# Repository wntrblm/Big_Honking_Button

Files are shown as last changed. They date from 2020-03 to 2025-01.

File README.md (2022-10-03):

# Winterbloom Big Honking Button

Winterbloom Big Honking Button is an open-source Eurorack module. You can find out more at https://honk.wntr.dev/.

## License and contributing

The code here is available under the [MIT License](firmware/LICENSE), the hardware designs are available under [CC BY-SA 4.0](hardware/LICENSE). I welcome contributors, please read the [Code of Conduct](CODE_OF_CONDUCT.md) first. :)

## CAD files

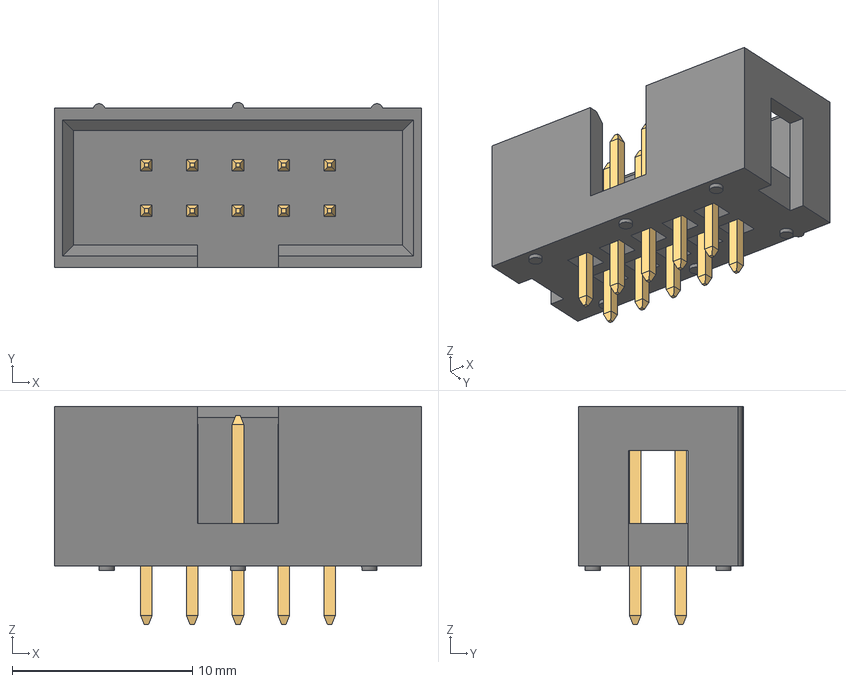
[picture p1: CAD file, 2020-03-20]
hardware/board/3dmodels/wurth-61201021621.step
20.4 x 9.18 x 12.1 mm
6120xx21621_PIN x 10

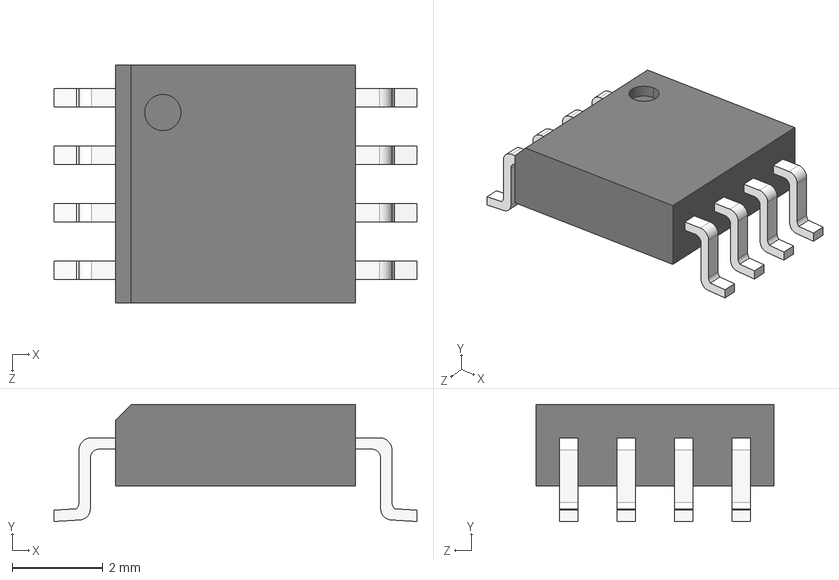
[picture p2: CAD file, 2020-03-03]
hardware/board/3dmodels/soic-8.step
8.00 x 2.58 x 5.25 mm

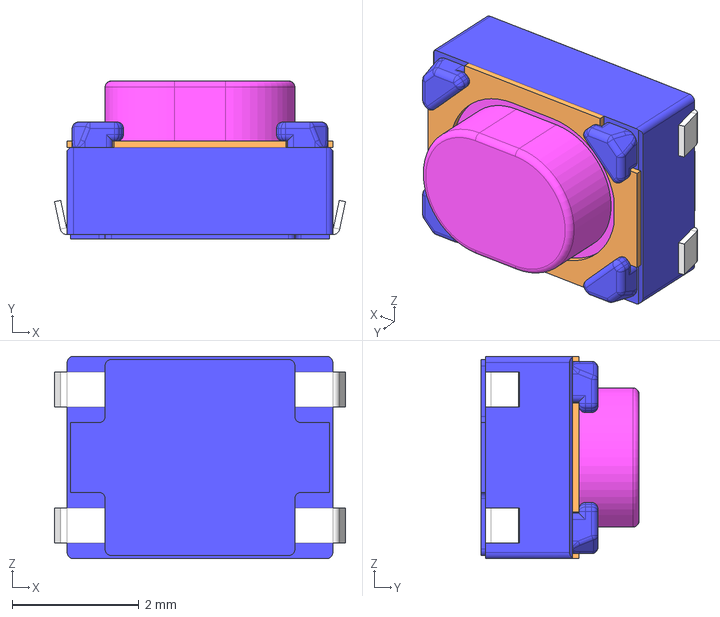
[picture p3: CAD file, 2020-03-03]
hardware/board/3dmodels/smt_tact.step
4.60 x 2.50 x 3.20 mm

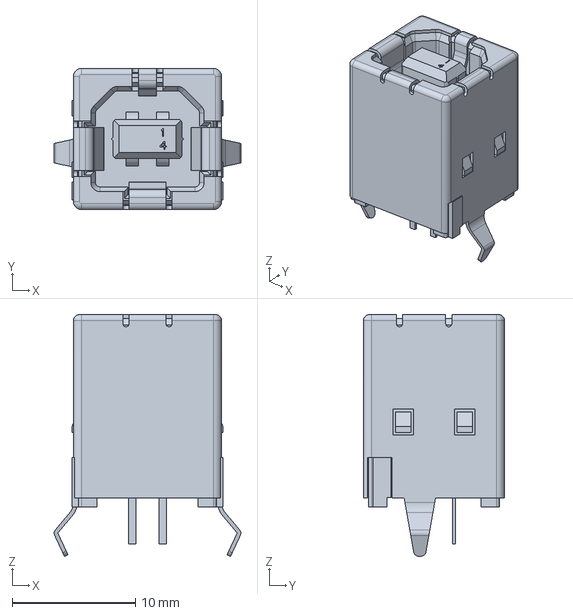
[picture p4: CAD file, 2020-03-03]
hardware/board/3dmodels/c-5787834-1-c-3d.step
15.1 x 11.5 x 19.6 mm

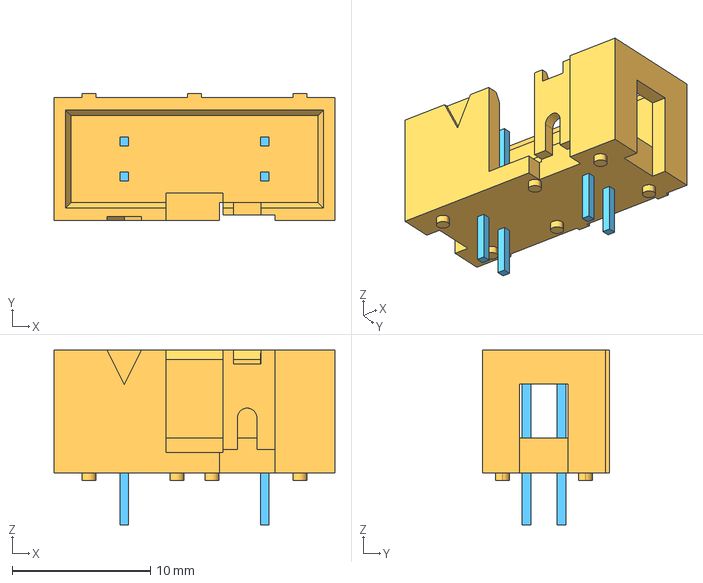
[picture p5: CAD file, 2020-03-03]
hardware/board/3dmodels/eurorack-power.step
20.3 x 9.20 x 12.6 mm

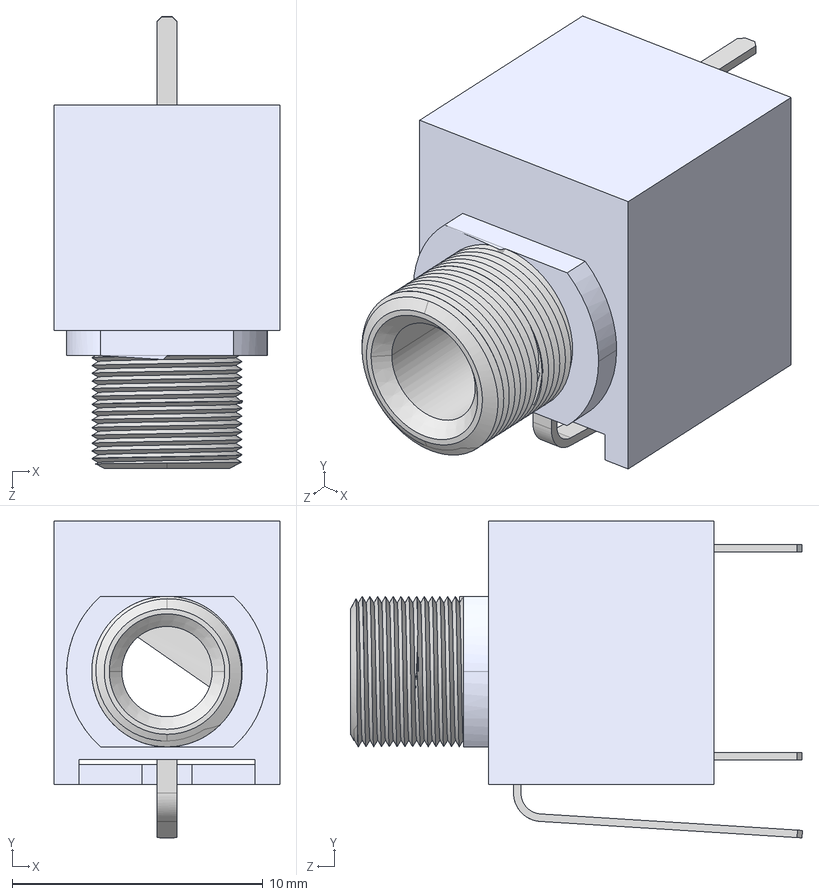
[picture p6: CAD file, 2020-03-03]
hardware/board/3dmodels/User Library-PJ301M-12 Thonkiconn v0_2.STEP
9.00 x 12.6 x 18.0 mm

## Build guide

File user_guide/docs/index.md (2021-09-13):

# Big Honking Button User Guide

Big Honking Button is, well, a big button that honks. Okay, that's not all- it’s actually a simple sampler in a very silly package. It has pitch CV, gate in, gate out, and you can store up to 4mb of samples on it.

## Getting support and help

We want you to have a wonderful experience with your module. If you need help or run into problems, please reach out to us. Email is the best way for product issues, whereas Discord and GitHub are great for getting advice and help on how to customize your module.

-   Send us [an email](mailto:support@winterbloom.com).
-   File a bug [on GitHub](https://github.com/wntrblm/Big_Honking_Button/issues)
-   Reach out on the [Discord][discord]

## Installing the module

To install this into your Eurorack setup:

1. Connect a Eurorack power cable to your power supply and the back of the module. **Note that even though the power connector on the module is keyed, double check that the red stripe is on the side labeled `red stripe`!**
1. Screw the module to your rack's rails.

## Inputs and outputs

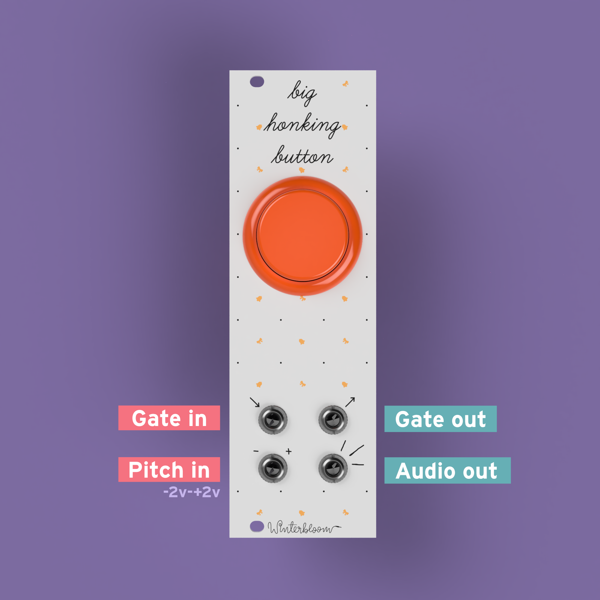
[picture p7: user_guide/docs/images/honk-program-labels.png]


Big Honking Button has two inputs:

-   A gate / trigger in
-   A pitch CV in that is 1v/Oct with a `-5v` to `+5v` range<sup>see note</sup>

And two outputs:

-   A gate / trigger out (`0v` or `5v`)
-   An audio out

With the default code, it will trigger the sample and play it through the audio out whenever the button is pressed or whenever the gate input is triggered. It will also set the gate out to high whenever the button is pressed or whenever the gate in is high. You can customize some of this behavior by [modifying the code](#modifying-the-code).

!!! note "Revision differences"
    Big Honking Buttons manufactured prior to 2021 (marked v4 on the backside) only have an input range of `-2v` to `+2v`. More than that won't damage the module, but it won't be able to measure anything outside of that range.

## Changing the sample

You can change the sample on Big Honking Button by connecting it to your computer via a micro USB cable. The USB port is located on the module's main circuit board, located under the panel. Please note that you do have to power the module in order for the USB connection to work - the module doesn't draw any power from the USB port.

Samples must be in mono, 16-bit, 44.1kHz, signed `wav` files. Adafruit has an [excellent guide on how to convert sound files](https://learn.adafruit.com/adafruit-wave-shield-audio-shield-for-arduino/convert-files), though your sample can be 44.1kHz and not 22kHz.

To modify the sample that plays:

1. Connect the Big Honking Button to your computer using a micro USB cable. It should show up as a small external drive named `CIRCUITPY`
1. Navigate to the `samples` folder in the drive
1. Rename or delete the existing `honk.wav` file
1. Copy your sample over and rename it to `honk.wav`

Your Big Honking Button will reboot and then it should play the new sample! If you run into trouble, please [reach out](#getting-support-and-help).

You can store and play multiple samples on the Big Honking Button, but to do that, you'll need to learn how to modify some of the code - don't worry! It's not too hard.

## Modifying the code

When connected to your computer, Big Honking Button shows up as a small drive named `CIRCUITPY`. In that drive, you should find a file named `code.py`. Big Honking Button runs [CircuitPython][circuitpython] which means that its firmware is written in the approachable [Python](https://python.org) programming language and you don't need any special knowledge or compilers to make changes to it. So, open up that file in your favorite text editor, we're going to make some changes!

If you don't have a text editor - that's okay! While you could use Notepad (Windows) or TextEdit (Mac), these can sometimes have issues with CircuitPython devices like Big Honking Button. I'd recommend [installing Mu](https://learn.adafruit.com/welcome-to-circuitpython/installing-mu-editor) if you're new to this whole world. You can read more about editing code for CircuitPython in [Adafruit's guide](https://learn.adafruit.com/welcome-to-circuitpython/creating-and-editing-code).

As a way to get your feet let's change how the Big Honking Button behaves. By default, when you press the button it plays the _entire_ sample, even if you release the button while the sample is still playing (this is **trigger mode**). This will make it where the sample will stop as soon as you let go of the button (or **gate** mode).

In the `code.py` you should see some code that looks like this (it's at the bottom):

```python
if bhb.released:
    bhb.gate_out = False
    # Uncomment the call to stop to make the sample
    # stop playing as soon as you release the button.
    # bhb.stop()
```

Modify this code so that it looks like this:

```python
if bhb.released:
    bhb.gate_out = False
    # Uncomment the call to stop to make the sample
    # stop playing as soon as you release the button.
    bhb.stop()
```

!!! warning "Be careful"
    Python is _whitespace-sensitive_. That means tabs and spaces are important! Make sure that you don't accidentally change the indentation level of this line.

Okay, save the file! Your Big Honking Button should restart and now it should stop the sample as soon as you let go of the button, try pressing it rapidly to see the effect.

!!! note "Tip"
    If things aren't working, see the section below on finding problems or [reach out](#getting-support-and-help)!

**Congrats**, you've made your first change to how the module works! 🎉

Big Honking Button can do all sorts of neat stuff by changing its code. Check out the [examples](#examples) or jump in the deep end with the [code reference](#code-reference). Don't be afraid to experiment and reach out if you need any help!

If you want to you can learn more about [CircuitPython](https://learn.adafruit.com/welcome-to-circuitpython/overview) to the most of your module. Also, please come chat on the [Discord][discord] where you can ask questions and see what others are doing with their Big Honking Button!

## Examples

Big Honking Button can do all sorts of things! We've made a few examples to show you some of the things it can do:
<video controls="" width="100%" style="margin: 1.5em 0;">
    <source src="https://storage.googleapis.com/files.winterbloom.com/marketing/honk-examples.mp4" type="video/mp4">
    Sorry, your browser doesn't support embedded videos.
</video>

To use these examples, connect your Big Honking Button to your computer just like you would when [modifying the code](#modifying-the-code). Once connected, copy the contents of the example you want to try (linked below) to `code.py` on the `CIRCUITPY` drive. **Be sure to save it as the correct name,** if you don't name it `code.py` it won't change anything. If you want to restore the original `code.py` it is [here](https://github.com/wntrblm/Big_Honking_Button/blob/main/examples/default.py).

1. [Cycle example](https://github.com/wntrblm/Big_Honking_Button/blob/main/examples/cycle.py): Shows how to load multiple samples and cycle between them.
1. [Random example](https://github.com/wntrblm/Big_Honking_Button/blob/main/examples/random.py): Shows how to load multiple samples and choose one at random.
1. [CV select example](https://github.com/wntrblm/Big_Honking_Button/blob/main/examples/cv_select.py): Shows how to load multiple samples and use the CV input to select which one to play.
1. [Press & release example](https://github.com/wntrblm/Big_Honking_Button/blob/main/examples/press_release.py) shows how to play a different sample when pressing the button and releasing the button.
1. [Separate button & gate example](https://github.com/wntrblm/Big_Honking_Button/blob/main/examples/button_gate.py) shows how to play a different sample depending on if the button was pressed or the gate in was triggered.
1. [Burst example](https://github.com/wntrblm/Big_Honking_Button/blob/main/examples/honk_burst.py) shows how to play a "burst" of samples when the button is pressed.
1. [Tap tempo example](https://github.com/wntrblm/Big_Honking_Button/blob/main/examples/tap_tempo.py): Shows how to use the button to set the tempo and have the module play back a sample at each beat.
1. [Sine example](https://github.com/wntrblm/Big_Honking_Button/blob/main/examples/sine.py): An advanced example that shows how to generate a custom waveform.
1. [Noise example](https://github.com/wntrblm/Big_Honking_Button/blob/main/examples/noise.py): An advanced example that shows how to generate noise.

If you're ready to go beyond the examples, check out the [code reference](#code-reference).

## Help! I changed some code and this thing isn't working!

There's probably some sort of error in the program. Don't worry, you can get it figured out.

If you connect using the [serial console](https://learn.adafruit.com/welcome-to-circuitpython/kattni-connecting-to-the-serial-console) you should be able to see the error. If you don't see it right away, you might need to reset the board (either by pressing the little button on the bottom of the module or power cycling your synth). Sometimes you can press `Ctrl+C` followed by `Ctrl+D` in the serial console to get the board to reset and tell you the error.

In any case, reach out on [Discord][discord] and we can walk you through figuring out what went wrong.

## Code reference

Big Honking Button runs [CircuitPython](https://circuitpython.org) and provides a helpful `BigHonkingButton` class for accessing the hardware and features. The first thing that you'll do in your code is import that class and create an instance:

```python
import winterbloom_bhb

bhb = winterbloom_bhb.BigHonkingButton()
```

In a lot of cases, the first thing you'll do with the `bhb` instance is load some samples:

```python
honk = bhb.load_sample("samples/honk.wav")
clap = bhb.load_sample("samples/clap.wav")
```

Once you're all set up, you'll start the **update loop**:

```python
while bhb.update():
    ...
```

This loop will repeat over and over. Each time the loop is run, `bhb.update()` is called and it will read in the state of the button, gate in, and CV input. You have to call `bhb.update()` otherwise it won't ever know if things change!

### Inputs

While inside the loop you can check the state of the various inputs. First, you can check if **either** the button has been pressed **or** the gate in has gone from low to high:

```python
if bhb.triggered:
    ...
```

Similarly, you can check if **either** the button has been released **or** the gate has gone from high to low:

```python
if bhb.released:
    ...
```

These two states are demonstrated in the [default example](https://github.com/wntrblm/Big_Honking_Button/blob/main/examples/default.py):

```python
while bhb.update():
    if bhb.triggered:
        bhb.play("honk.wav")

    elif bhb.released:
        bhb.stop()
```

You can get more specific by checking the button and gate independently. You
can use the `button` property to check the button:

```python
if bhb.button.pressed:
    # Button was just pressed.
    ...

if bhb.button.released:
    # Button was just released.
    ...

if bhb.button:
    # Button is held down.
```

Likewise, you can use the `gate_in` property to check the gate input:

```python
if bhb.gate_in.rising_edge:
    # Gate in just moved from low to high.
    ...

if bhb.gate_in.falling_edge:
    # Gate in just moved from high to low.
    ...

if bhb.gate_in:
    # The gate input is being held high.
```

!!! Note "Aliases"
    For convenience, `bhb.button` and `bhb.gate_in` have property aliases. `.pressed`, `.rising_edge`, and `.triggered` are all the same, likewise, `.released` and `.falling_edge` are the same.

The pitch CV input is a little different. You can use `bhb.pitch_in` to read the *voltage* on the pitch CV input. Remember, the input range is `-5v` to `+5v`.

```python
if bhb.pitch_in > 0:
    ...
```

More usefully you can use the pitch input to re-pitch the sample:

```
bhb.play(honk, pitch_cv=bhb.pitch_in)
```

There are other ways you can use the CV input, for instance, the [CV select example](https://github.com/wntrblm/Big_Honking_Button/blob/main/examples/cv_select.py) uses it to select from a list of samples.

### Outputs

Big Honking Button has two outputs: an audio out and a gate out. The audio out can be used to play previously-loaded samples:

```python
bhb.play(honk)
```

It can also play the sample repeatedly:

```python
bhb.play(honk, repeat=True)
```

And re-pitch the sample:

```python
# Play at twice the frequency
bhb.play(honk, pitch_cv=2.0)

# Play at half the frequency
bhb.play(honk, pitch_cv=0.5)

# Play at normal pitch
bhb.play(honk, pitch_cv=1.0)
```

By default, the sample will play all the way through. If you want to stop the
sample you can use `bhb.stop()`:

```python
if bhb.pressed:
    bhb.play(some_long_sample)

elif bhb.released:
    bhb.stop()
```

When `stop()` is called the sample stops playing immediately - even if its in the middle of playback. If you play a new sample while a sample is playing, the old sample will stop immediately and the new one will start playing.

Finally, there's the gate out:

```python
if bhb.pressed:
    # Sets the output to +5v
    bhb.gate_out = True

elif bhb.released:
    # Sets the output to 0v
    bhb.gate_out = False
```

## Updating the firmware

Updating the firmware requires two steps: Updating CircuitPython and updating Big Honking Button's libraries.

### Updating CircuitPython

1. [Download the latest version of CircuitPython for Winterbloom Big Honking Button](https://circuitpython.org/board/winterbloom_big_honking_button/).
1. Connect Big Honking Button to your computer via USB. The USB port is located underneath the panel. Note that you still have to power the module from a Eurorack power supply.
1. Place Big Honking Button in bootloader mode by pressing the reset button twice quickly. The reset button is located on the bottom of the module just below the power connector. Once in bootloader mode, you should see a drive on your computer named `HONKBOOT`.
1. Copy the `uf2` file from step 1 to the `HONKBOOT` drive. The module should restart by itself.

### Updating Big Honking Button's libraries

1. [Download the latest release bundle for Big Honking Button](https://github.com/wntrblm/Big_Honking_Button/releases).
2. Unzip the release bundle, and then copy the contents to Big Honking Button's `CIRCUITPY` drive, replacing any existing files.
3. Reboot Big Honking Button by power cycling your synthesizer or pressing the reset button again.

<!-- ## Frequently asked questions

Got a question not answered here? [Reach out](#getting-support-and-help), we'll be happy to help! -->

## Open source hardware & software

Big Honking Button is completely open source and hacking is encouraged.

-   The [firmware](https://github.com/wntrblm/Big_Honking_Button/tree/main/firmware) is available under the [MIT License](https://github.com/wntrblm/Big_Honking_Button/blob/main/firmware/LICENSE).
-   The [hardware design](https://github.com/wntrblm/Big_Honking_Button/tree/main/hardware) is available under the [CC BY-SA 4.0 License](https://github.com/wntrblm/Big_Honking_Button/blob/main/hardware/LICENSE) and is designed using [KiCAD](https://kicad.org/) which is free and open-source. You can open the hardware files using KiCAD or you can check out a [PDF of the schematic](https://github.com/wntrblm/Big_Honking_Button/raw/main/hardware/board/board.pdf).
-   [CircuitPython][circuitpython] is available under the [MIT License](https://github.com/adafruit/circuitpython/blob/main/LICENSE).

Open Source Hardware Association mark Big Honking Button is [certified open source hardware](https://certification.oshwa.org/us000678.html).

## Warranty, disclaimers, and limits

Modules purchased from Winterbloom have a warranty of six months from the date of purchase. This warranty covers any manufacturing defects in the module. It does not cover damage from due to incorrect handling, storage, or power, overvoltage events, or modifications.

Please [contact us](mailto:support@winterbloom.com) if you are experiencing issues with your module. Modules returned under warranty will either be refunded, replaced, or repaired at our discretion. You will be responsible for the cost of returning the module to Winterbloom.

Because Eurorack has a vast number of possible combinations of power supplies, modules, cases, and accessories, it is impossible for us to guarantee compatibility with every possible configuration. We make a reasonable effort to test modules with several power supplies, cases, and other modules.

We encourage tinkering, however, we will not refund, repair, or replace any products that have been modified.

## Acknowledgments and thanks

Big Honking Button would not be possible without the help of the CircuitPython community and Adafruit Industries.

[circuitpython]: https://circuitpython.org
[discord]: https://discord.gg/UpfqghQ

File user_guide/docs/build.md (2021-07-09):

# Big Honking Button Kit Build Guide

Welcome to the build guide for the Big Honking Button! We hope you have a great time putting this module together and a wonderful time using it.

Please read all instructions thoroughly before starting. If you have questions or run into trouble please reach out to us on [discord] or drop us an email at support@winterbloom.com

This build is a **beginner level** kit. Some soldering experience is helpful but not required. If it's your first time soldering we recommend reading through [Adafruit's guide to excellent soldering](https://learn.adafruit.com/adafruit-guide-excellent-soldering). This build takes around **two hours** to complete.

## Tools and materials required

Before jumping in, make sure you have:

* A soldering iron, like [this one](https://www.adafruit.com/product/180)
* Solder, we can recommend [Adafruit's 60/40 **no-clean** rosin core solder](https://www.adafruit.com/product/145). We suggest using soldering with "no clean" flux. If you do use a different kind of flux, be sure to carefully clean the flux residue off based on the guidelines provided by the manufacturer of your solder.
* A lighter, candle, or some other heat source for the shrink wrap. A [hot air station](https://www.adafruit.com/product/1869) is ideal, not not necessary.

## Kit contents

Your kit should contain the following items. If any are missing please email us at support@winterbloom.com.

<object
    alt="Kit contents"
    data-is-svg-map
    data-list="kit-contents-img-datalist"
    data-stylesheet="/styles/kit-contents-svgmap.css"
    data-info-text-template="kit-contents-img-info-text"
    data="/images/kit/1-kit.svg"
    height="100%"
    id="kit-contents-img"
    type="image/svg+xml"
    width="100%">
</object>
<template id="kit-contents-img-info-text">
    <g id="info-text-container">
        <rect data-size-to="info-text"></rect>
        <text id="info-text">Test test test</text>
    </g>
</template>
<datalist id="kit-contents-img-datalist">
    <option value="power-cable">Eurorack power cable (1)</option>
    <option value="panel">Front panel (1)</option>
    <option value="retainer">Retaining ring (1)</option>
    <option value="pcb">Mainboard (1)</option>
    <option value="wire-harness">Wiring harness (1)</option>
    <option value="jst">JST header (1)</option>
    <option value="rubber-band">Rubber band (1)</option>
    <option value="screws">M3x6 screws (2)</option>
    <option value="heat-shrink">Heat shrink (2)</option>
    <option value="nuts">Hex nuts for the 1/8" jacks (4)</option>
    <option value="jacks">1/8" jacks (4)</option>
    <option value="power-header">Eurorack power header (1)</option>
    <option value="button">SANWA arcade button (1)</option>
</datalist>
<script type="module" src="/scripts/svgmap.js"></script>
<link rel="stylesheet" href="/styles/svgmap.css"/>

- (1) Panel
- (1) SANWA arcade button
- (1) Big Honking Button mainboard
- (1) Button wiring harness
- (2) Short pieces of heat-shrink tubing
- (1) 10-pin Eurorack power connector (black)
- (1) 2-pin JST header (green)
- (4) 1/8" jacks
- (4) Hex nuts for the 1/8" jacks
- (1) Retaining ring (colors vary)
- (1) Rubber band
- (1) Eurorack power cable
- (2) M3 screws for attaching the module to your rack

We program, test, and calibrate the mainboard before sending it to you, so you don't have to worry about any of that- once you're done building you'll be good to go!

# Soldering the jacks

The first step is to solder the 1/8" jacks on to the mainboard.

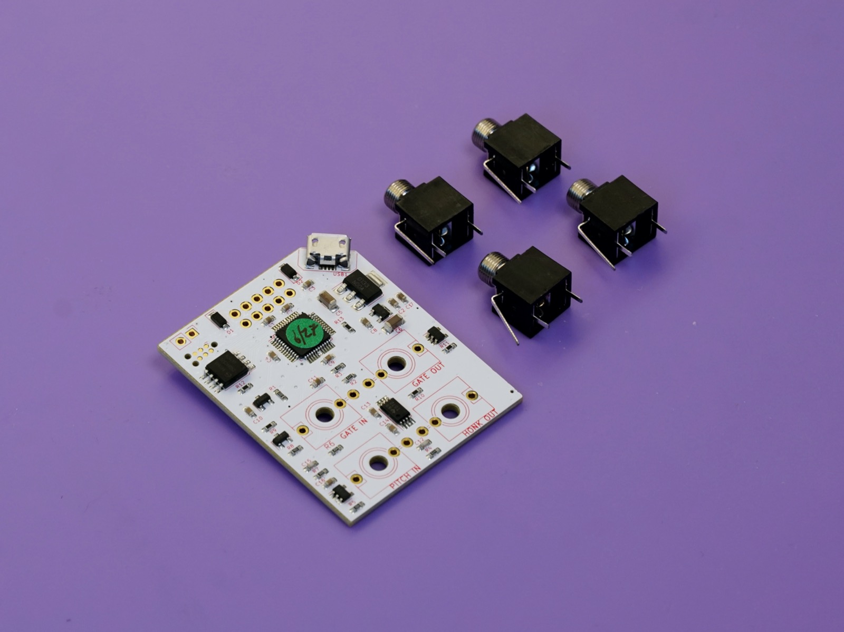
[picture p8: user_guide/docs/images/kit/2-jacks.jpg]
Jacks and printed circuit board


Place the jacks onto the **front** side of the board. The front side has the outline of the jacks printed on it, so it should be easy to spot!

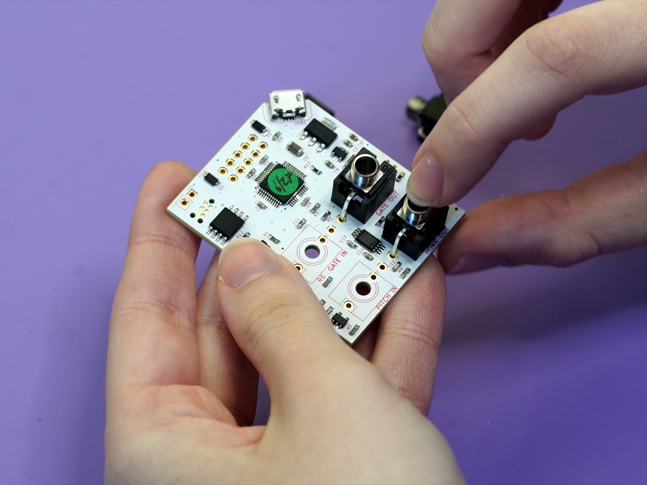
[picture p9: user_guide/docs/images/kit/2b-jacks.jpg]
Placing jacks on the board


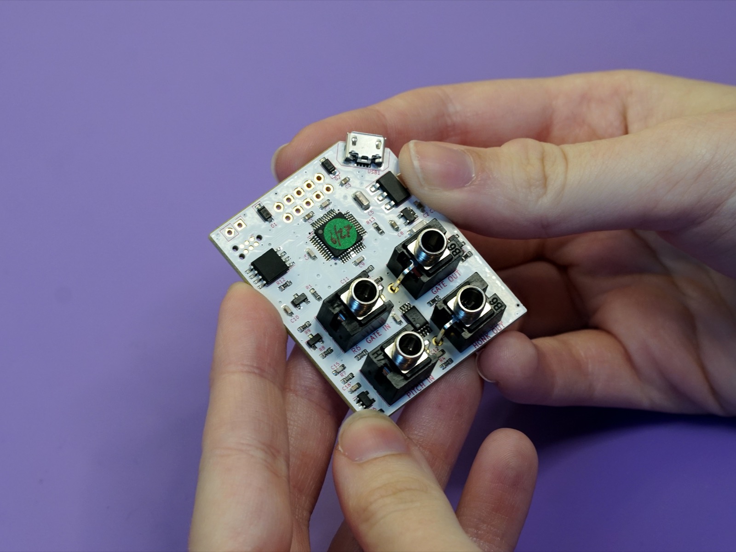
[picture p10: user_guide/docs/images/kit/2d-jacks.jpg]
Jacks placed onto the board


Once the jacks are placed, you can use the panel to hold them in place while soldering them. Place the panel over the top of the jacks:

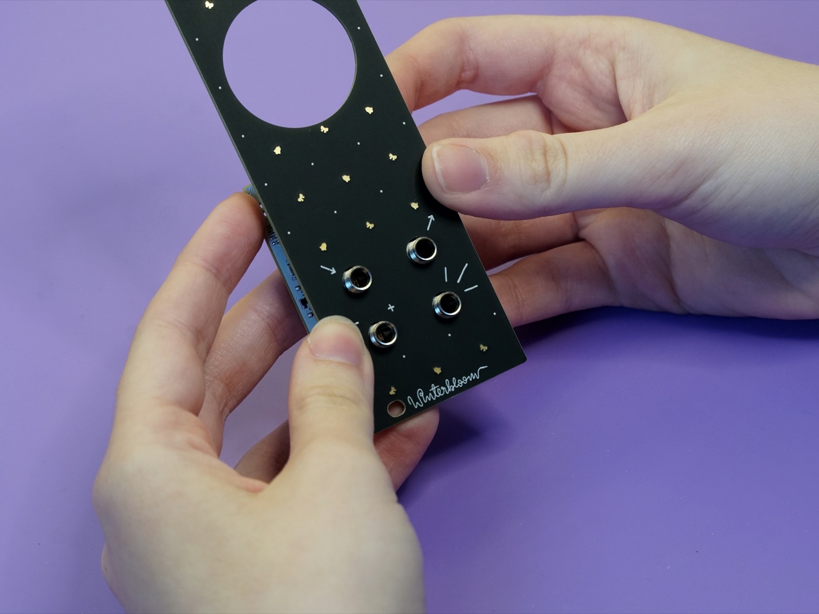
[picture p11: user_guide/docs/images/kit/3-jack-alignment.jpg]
Panel over jacks


The use the rubber band to hold the panel onto the jacks and board. Place it between the two rows of jacks.

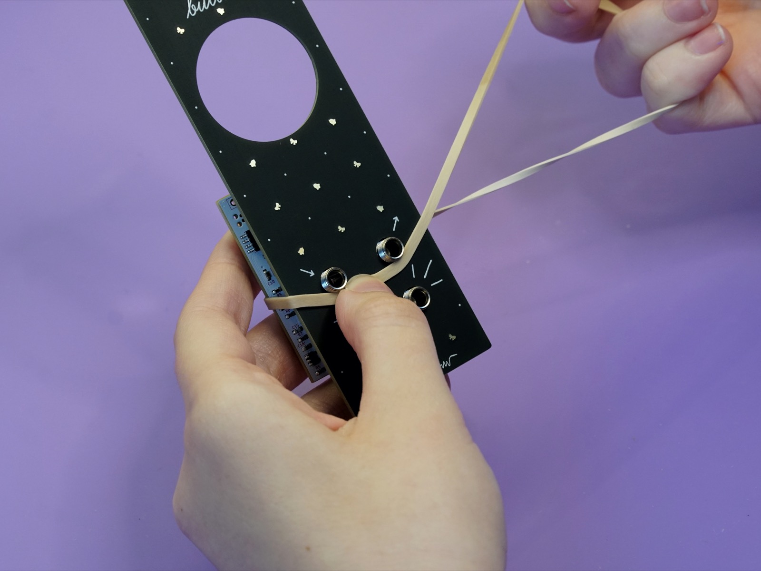
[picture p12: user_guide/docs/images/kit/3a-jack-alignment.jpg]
Rubber band placed


Double (or triple) it over to make sure it's taut.

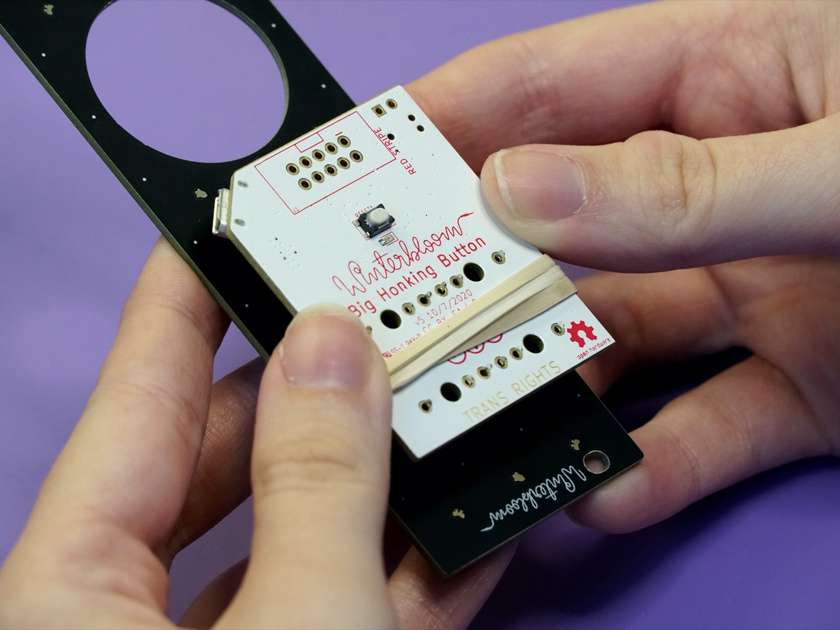
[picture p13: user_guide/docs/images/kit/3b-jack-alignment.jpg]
Rubber band pulled taught


!!! note "Tip"
    Make sure that the jacks are flush against the board before soldering. You can double-check after each solder joint and adjust them if necessary.

Now you can solder each of the pins from the jacks to the board. Take care not to burn the rubber band.

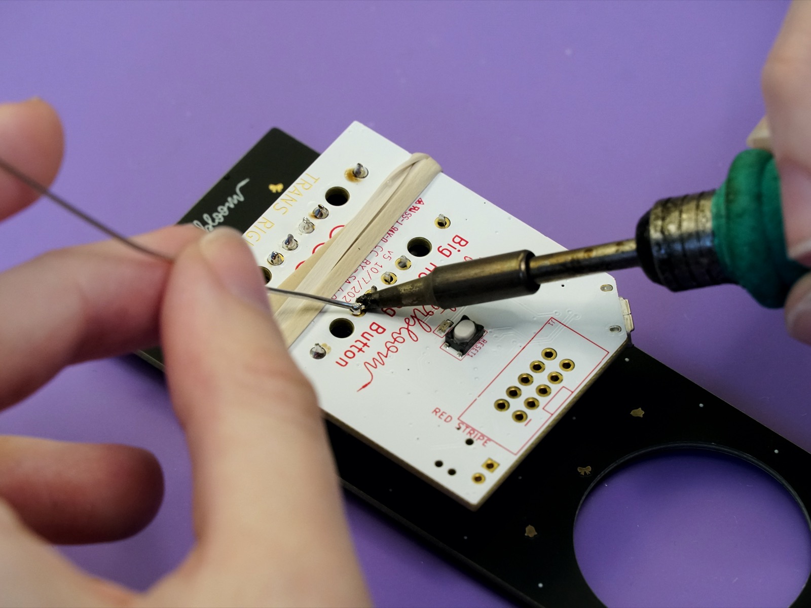
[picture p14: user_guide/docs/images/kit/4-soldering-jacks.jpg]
Soldering the jacks


There are three solder joints per jack for a total of twelve.

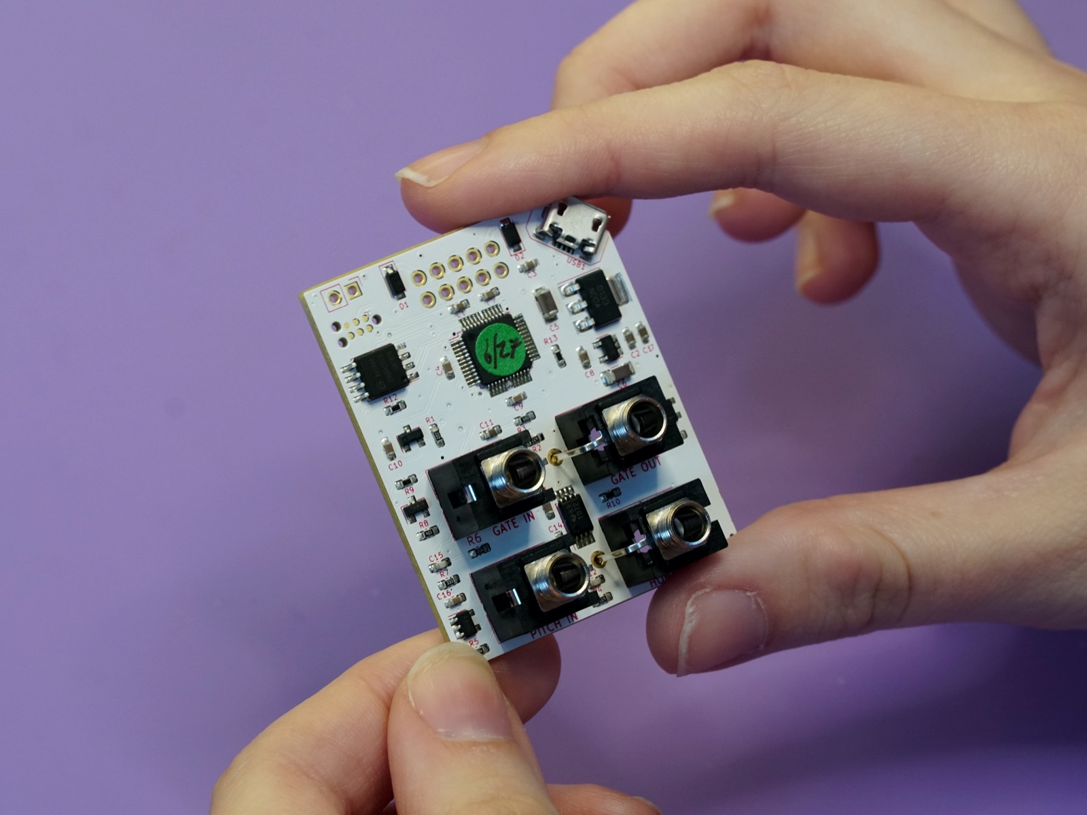
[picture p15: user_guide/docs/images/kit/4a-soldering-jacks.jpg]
Soldering the jacks


# Soldering the JST connector

Next you'll need to solder the green JST connector to the PCB.

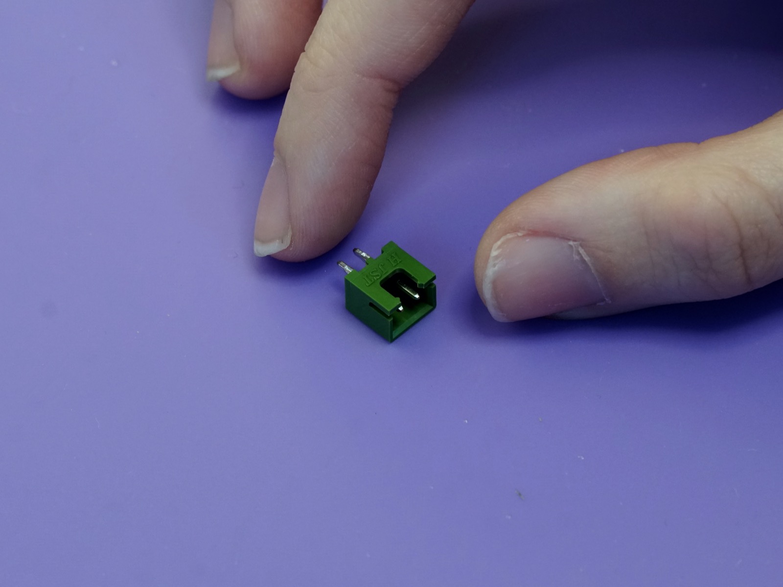
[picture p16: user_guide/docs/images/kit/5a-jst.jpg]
JST Connector


Unlike the jacks, The JST connector goes on the **back** side of the board, next to where the power header goes.

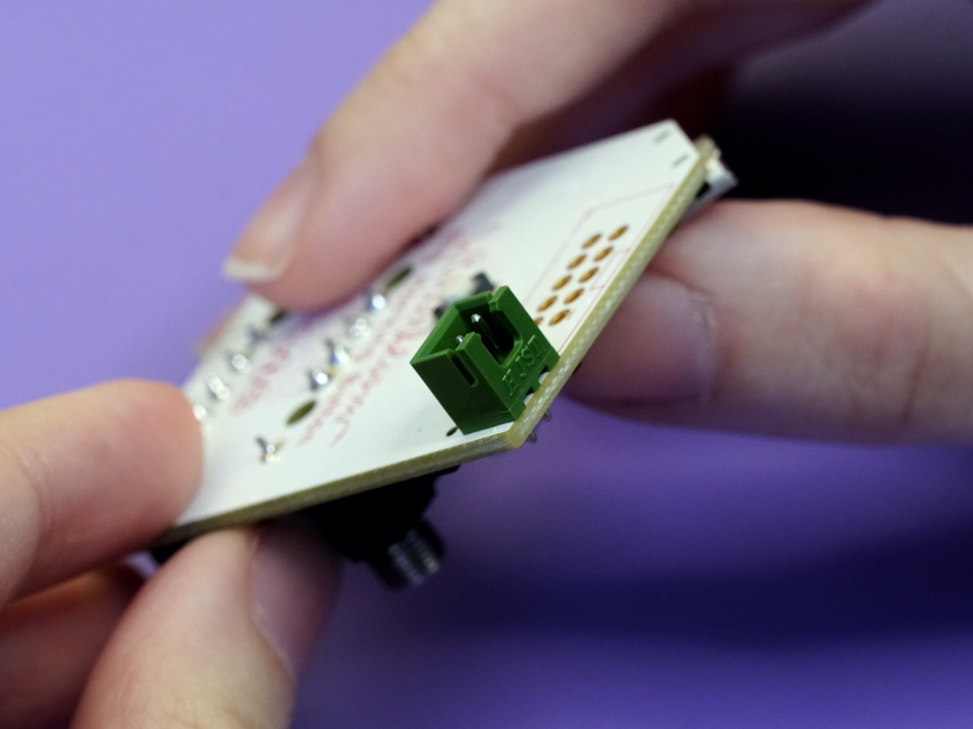
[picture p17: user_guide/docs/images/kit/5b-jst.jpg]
JST Connector placed


Pay special attention to the orentation of the JST connector. It only goes on correctly one way- It shouldn't be overhanging the board, it should come right up to the edge.

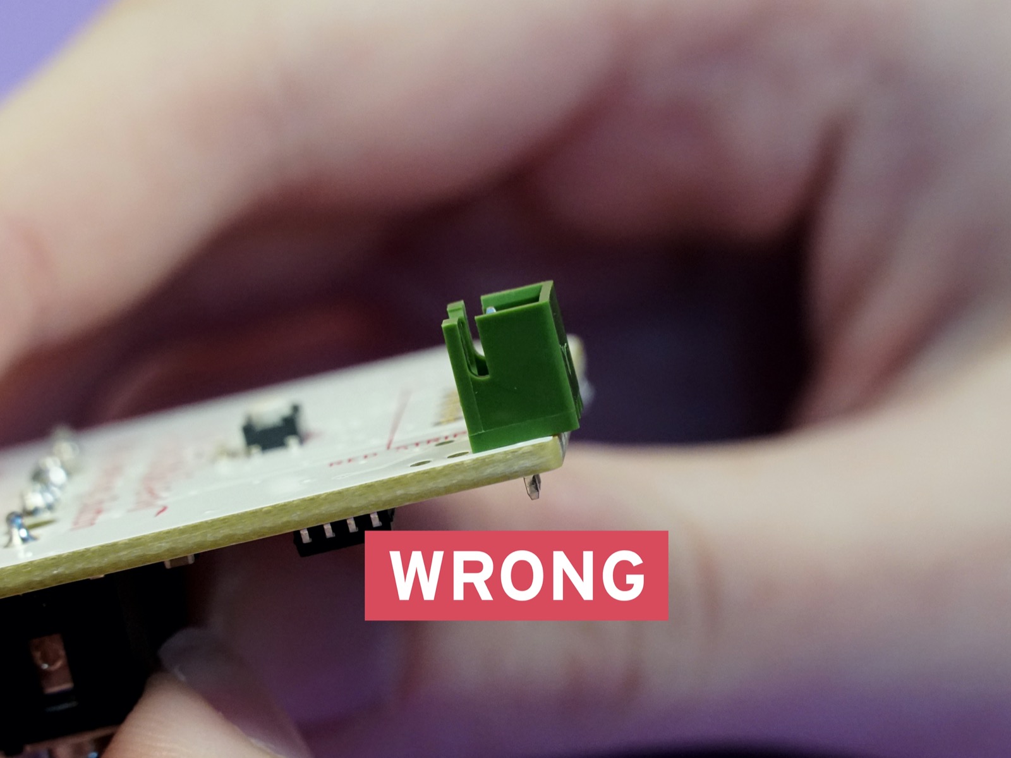
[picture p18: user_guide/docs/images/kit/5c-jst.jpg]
Correct placement of connector

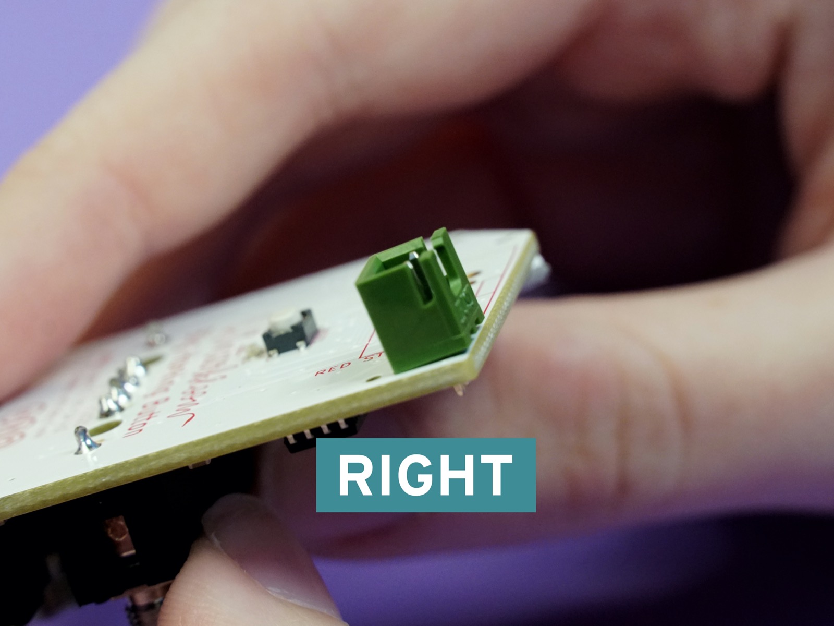
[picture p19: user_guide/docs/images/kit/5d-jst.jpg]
incorrect placement of connector


Just like with the 1/8" jacks, flip the board over and solder the two pins of the JST connector to the board. Make sure the connector is flush with the board after making the first solder joint. If needed, you can use a piece of tape to hold it in place.

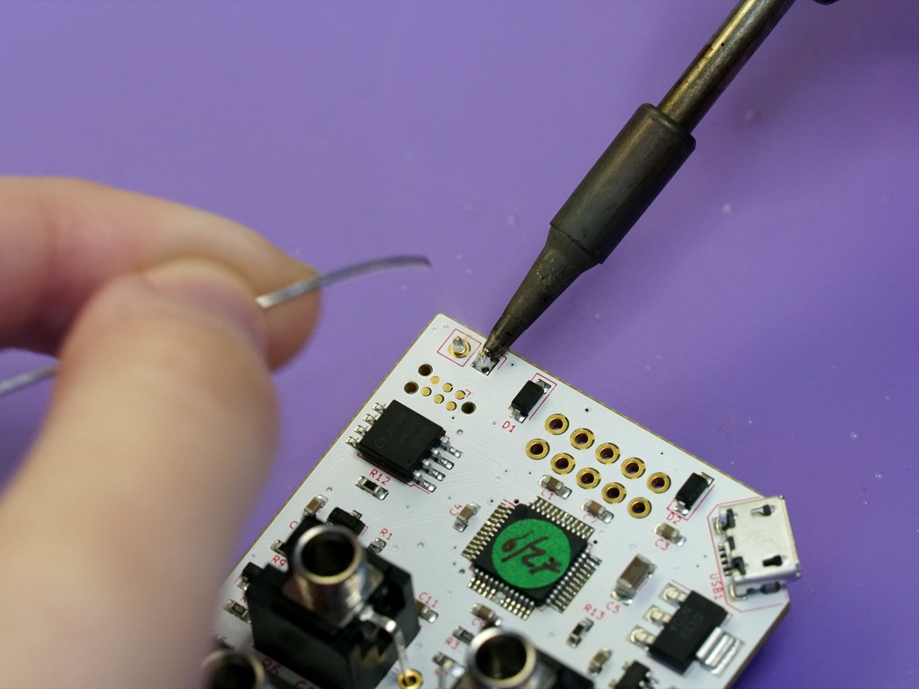
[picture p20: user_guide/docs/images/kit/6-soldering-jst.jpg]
Soldering the JST header


## Soldering the power connector

Next up is the 10-pin Eurorack power connector.

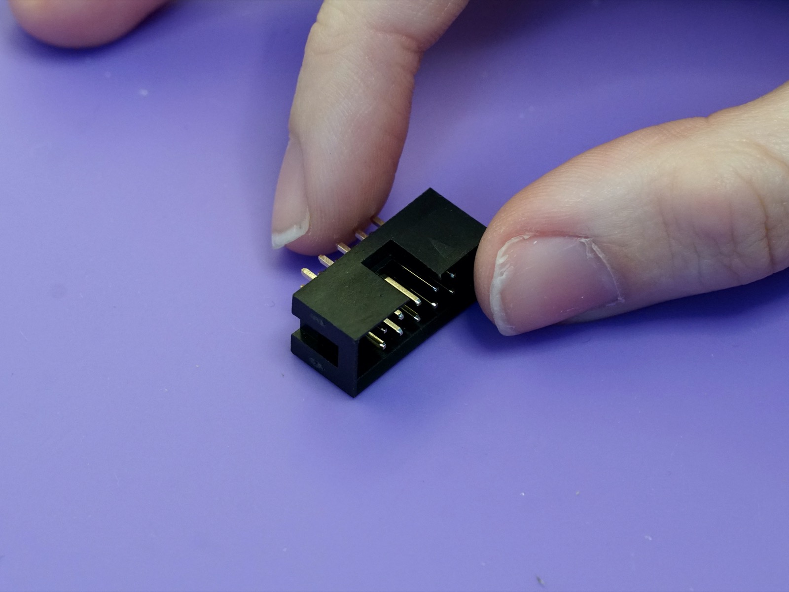
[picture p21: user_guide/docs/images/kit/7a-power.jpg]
Power connector


The power connector also goes on the **back** side of the board. When placing **note the notch in the outline on the board**. You'll need to make sure the **slot on the connector matches where the notch is on the outline**. The slot should be facing the edge of the board.

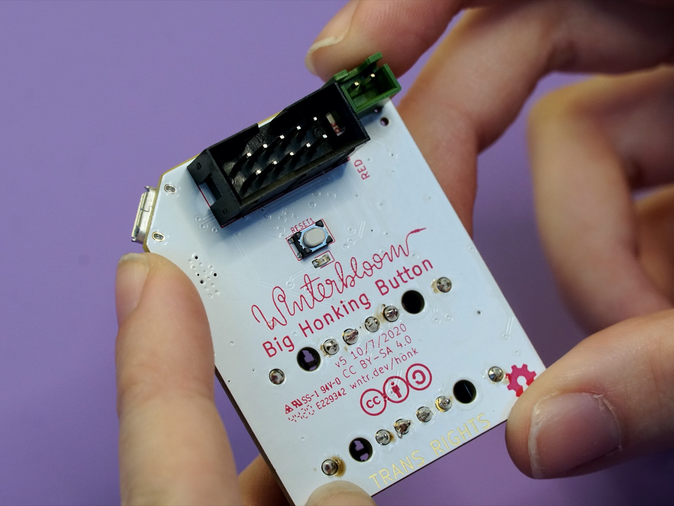
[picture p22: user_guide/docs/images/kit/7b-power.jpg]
Power connector placed


Once placed you can solder the 10 pins on the other side of the board. Be careful here and avoid touching the small components near the pins with your iron. Check and make sure the connector is flush with the board as you go.

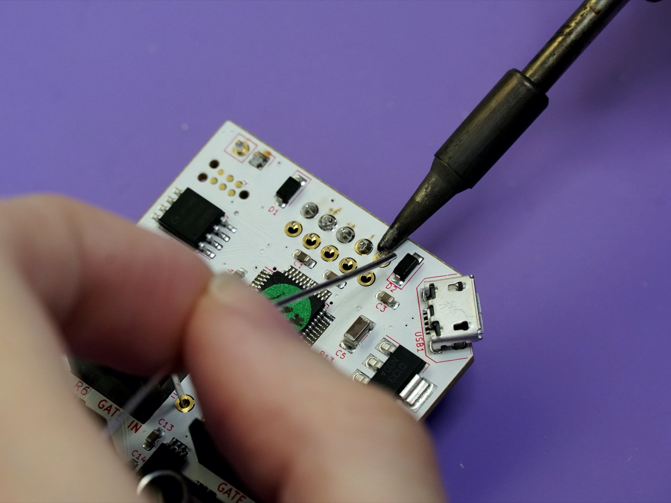
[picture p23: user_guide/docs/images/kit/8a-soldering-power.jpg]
Power connector soldering


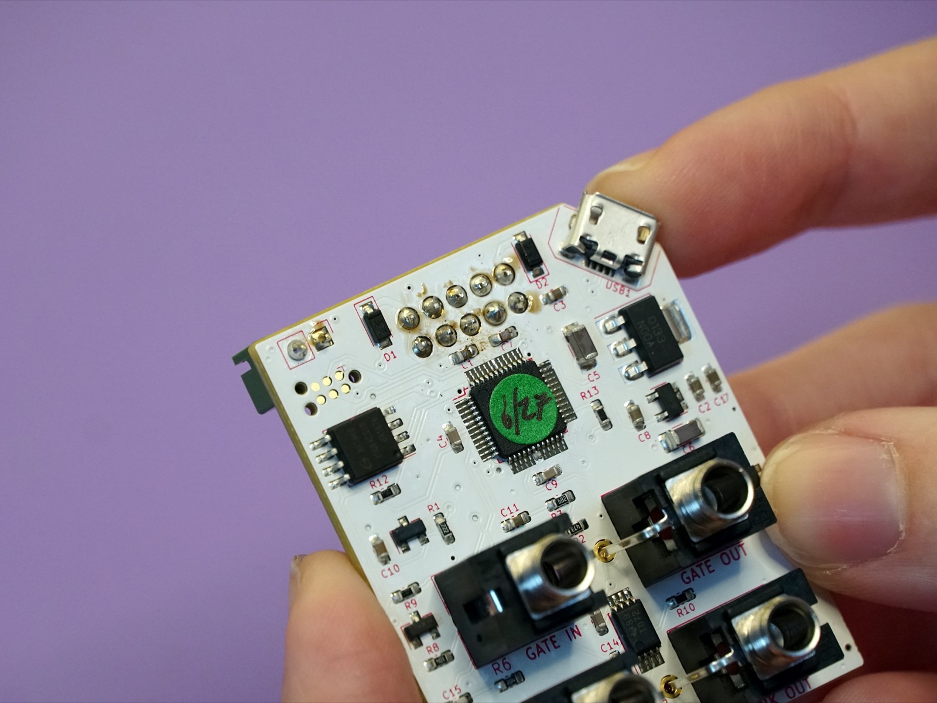
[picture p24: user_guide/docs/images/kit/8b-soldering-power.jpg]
Power connector soldered


## Soldering the wire harness to the button

Set the board aside for a moment because the next step is to attach the wire harness to the button. You'll need the button, wire harness, and the two small pieces of heat shrink tubing.

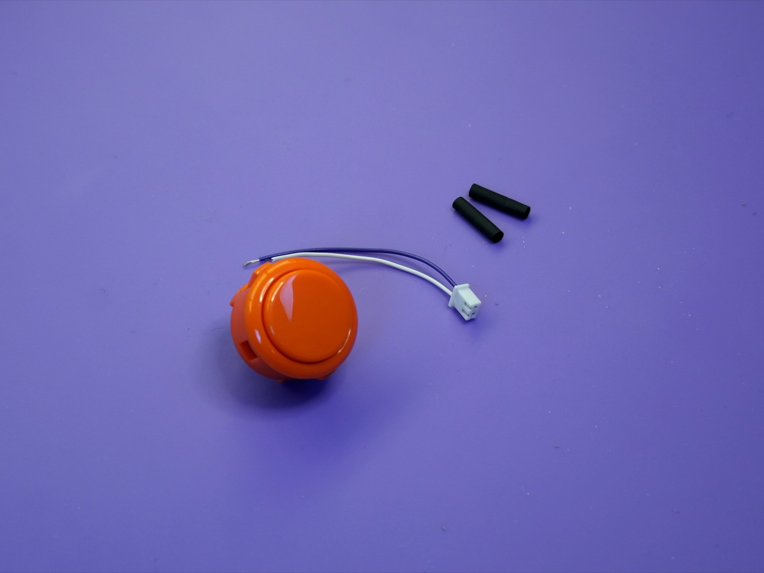
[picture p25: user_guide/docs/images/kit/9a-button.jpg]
Wire harness, button, and heat shrink tubing


First, place the two pieces of heat-shrink tubing onto the two wires on the wire harness. Push them all the way to the white connector for now.

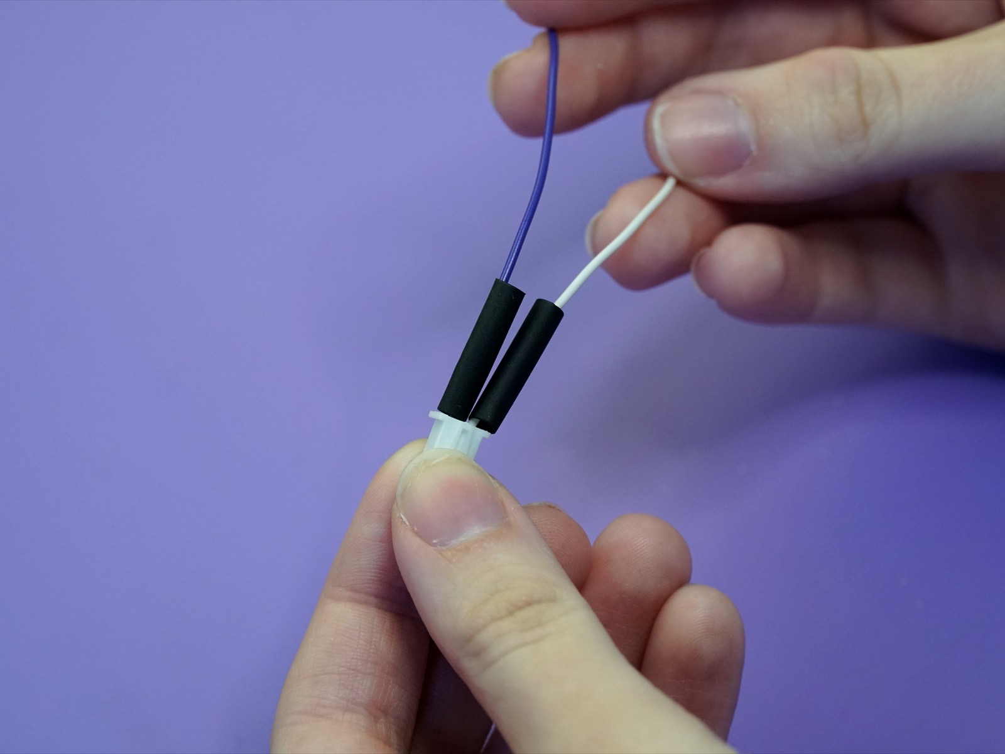
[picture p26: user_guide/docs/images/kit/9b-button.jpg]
Heat-shrink placed on harness


Carefully solder the wires from the harness onto the lugs on the button one at a time. You may need to get a friend to hold the button for you to keep it from moving around. Make sure the heat-shrink tubing stays on the wires.

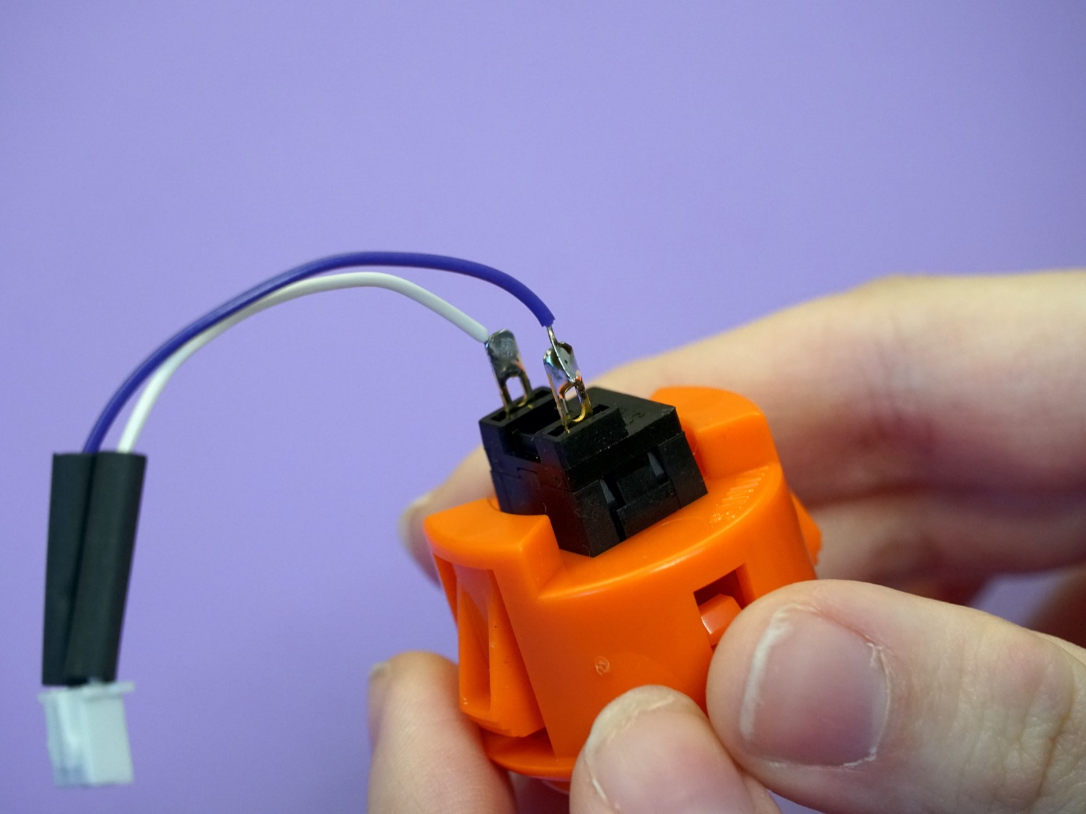
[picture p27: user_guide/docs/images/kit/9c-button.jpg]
Button soldered


Now you can push the heat-shrink tubing over the solder joints and the lugs to cover the connections. Use your lighter, candle, hot air station to shrink the tubing over the connectors.

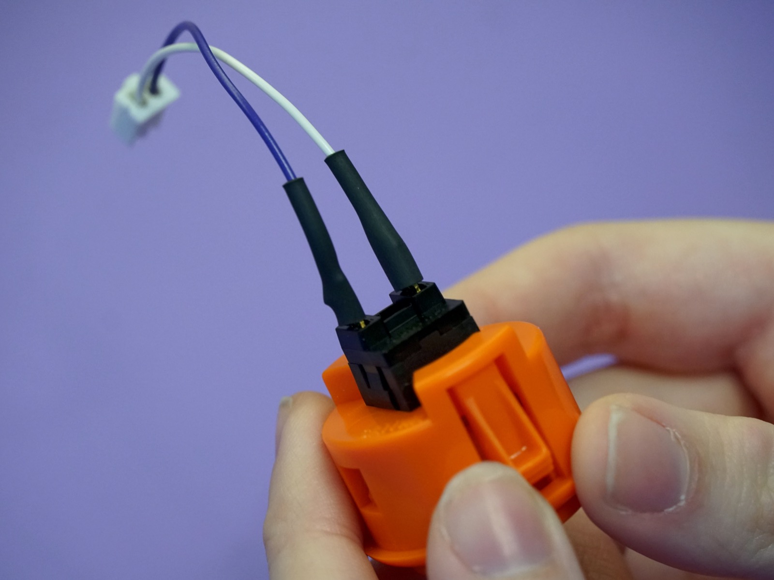
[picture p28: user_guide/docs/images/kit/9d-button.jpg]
Button soldered


!!! warning "Careful"
    The heat shrink will not completely shrink around the wire side so **do not** apply excess heat - you can melt the wire's sleeving. If using a hot air station set the temperature to no higher than 150°C.

## Putting the button in the panel

All of the soldering is complete! You can put away the soldering iron.

The next step it to place the button snugly into the panel. Push the wires through the big hole in the panel:

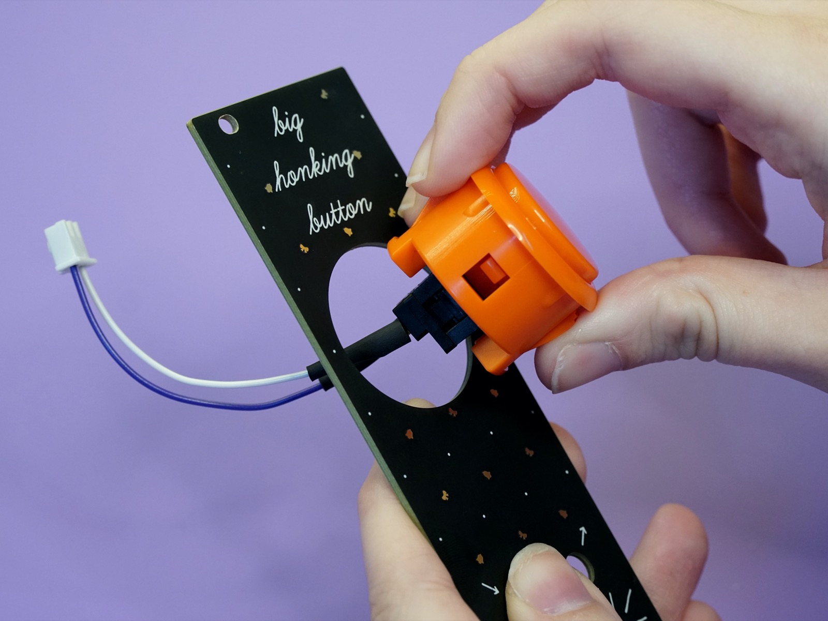
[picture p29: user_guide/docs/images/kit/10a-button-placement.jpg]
Button wires through panel


Then push the button into the hole - it should snap into place.

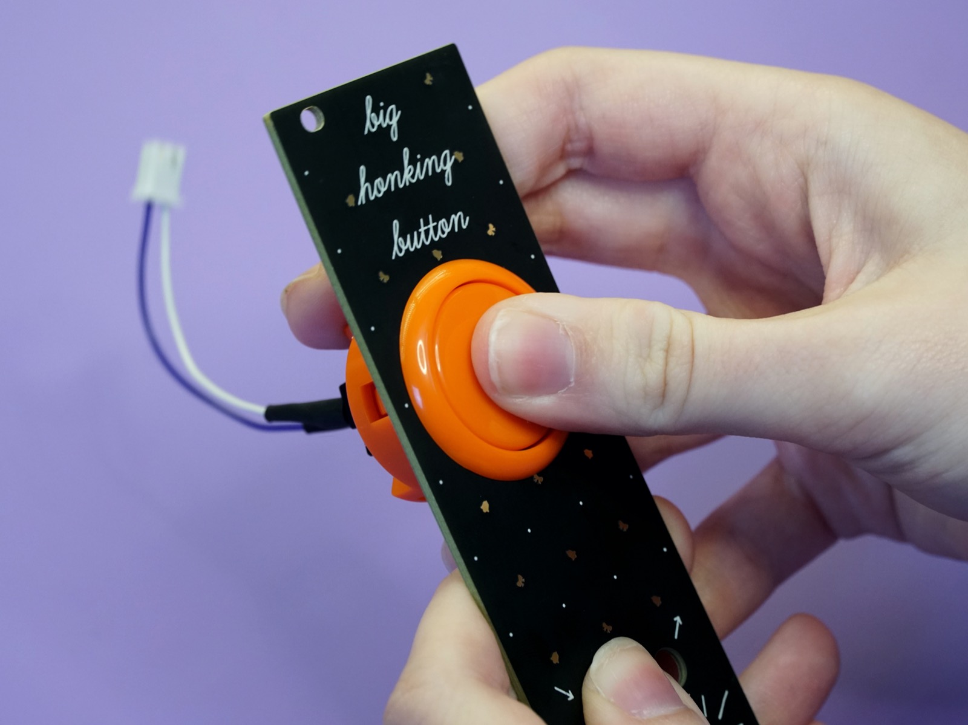
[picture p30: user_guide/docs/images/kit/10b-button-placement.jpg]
Button in panel


Flip the panel over so that you can see the back part of the button and grab the small plastic retaining ring. Note that your ring might be a different color:

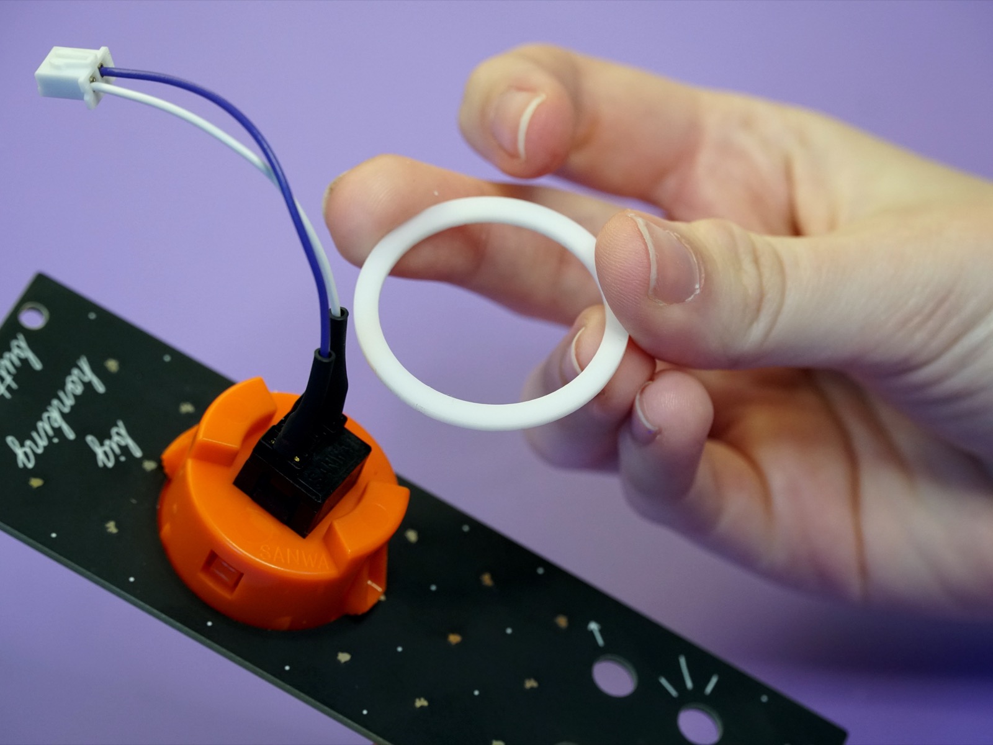
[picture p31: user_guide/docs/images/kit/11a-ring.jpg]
Retaining ring


Slip the ring over the wires:

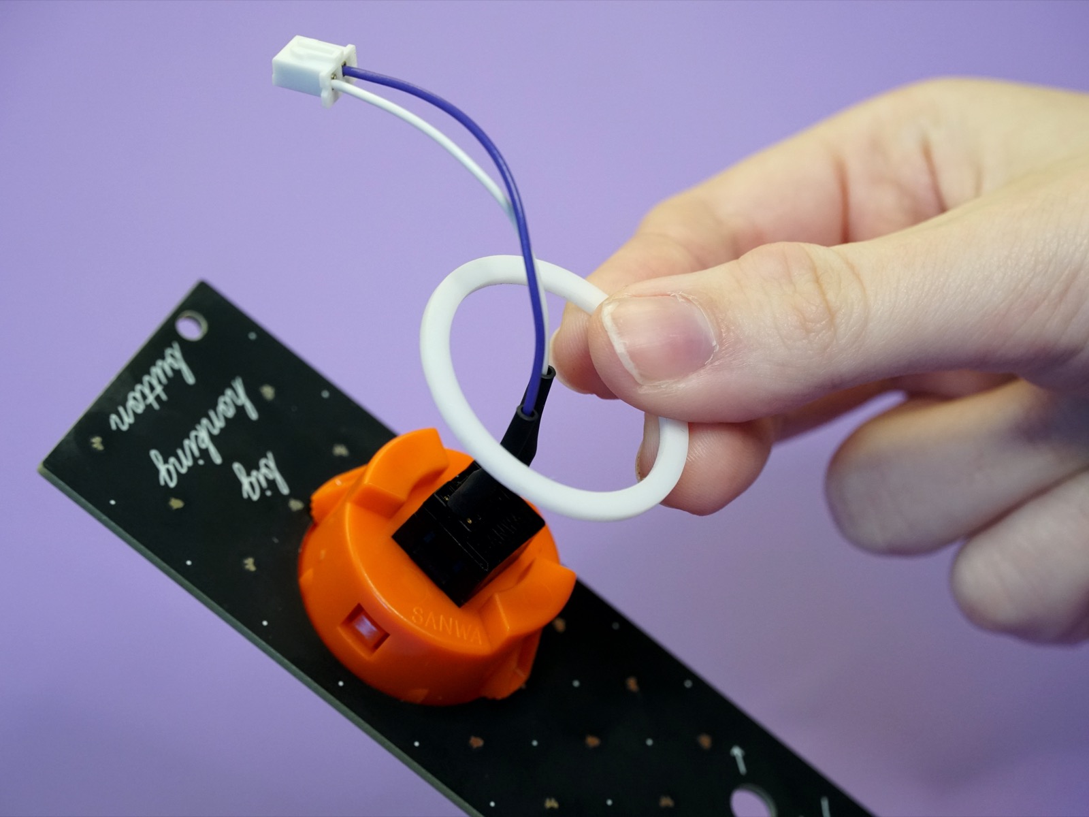
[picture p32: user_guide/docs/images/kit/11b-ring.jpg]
Retaining ring through wires


And then push the ring firmly over the button. It should click into place with a satisfying snap and the button should now be snug as a bug in a rug.

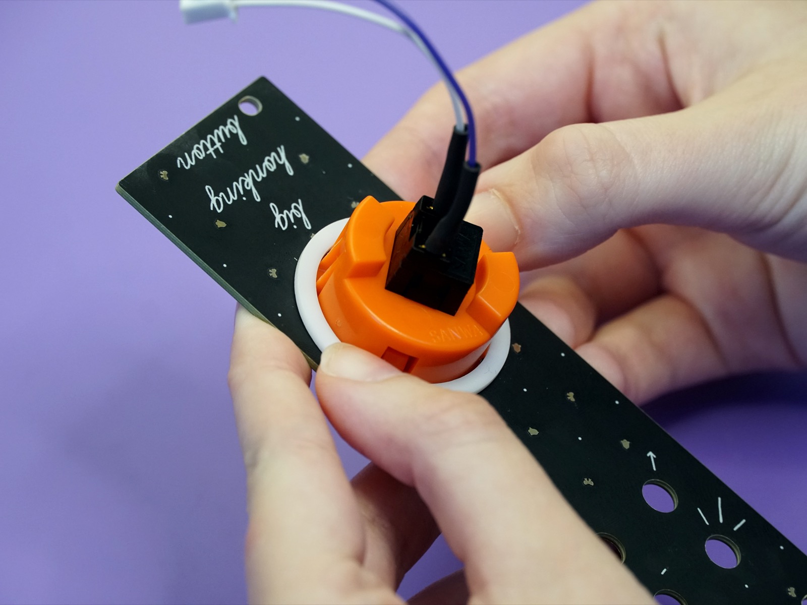
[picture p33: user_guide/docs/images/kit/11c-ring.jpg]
Retaining ring in place


## Secure the panel

Now that the button is in place you can secure the panel to the mainboard. Just like you did when soldering on the jacks, place the panel over the jacks and push them through the panel:

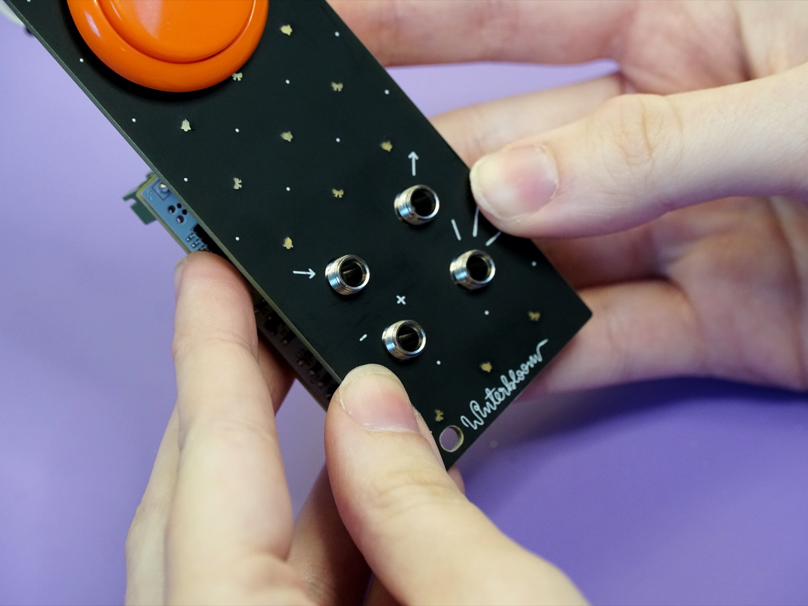
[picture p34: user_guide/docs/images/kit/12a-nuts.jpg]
Jack and panel


Now take the hex nuts and screw them onto the jacks:

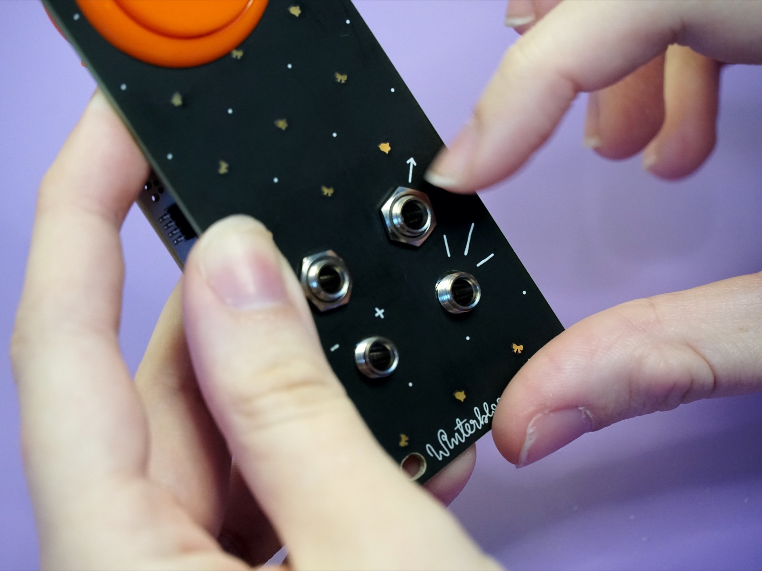
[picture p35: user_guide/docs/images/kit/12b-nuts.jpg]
Placing hex nuts on the panel


Don't over-tighten - finger tight is generally good enough.

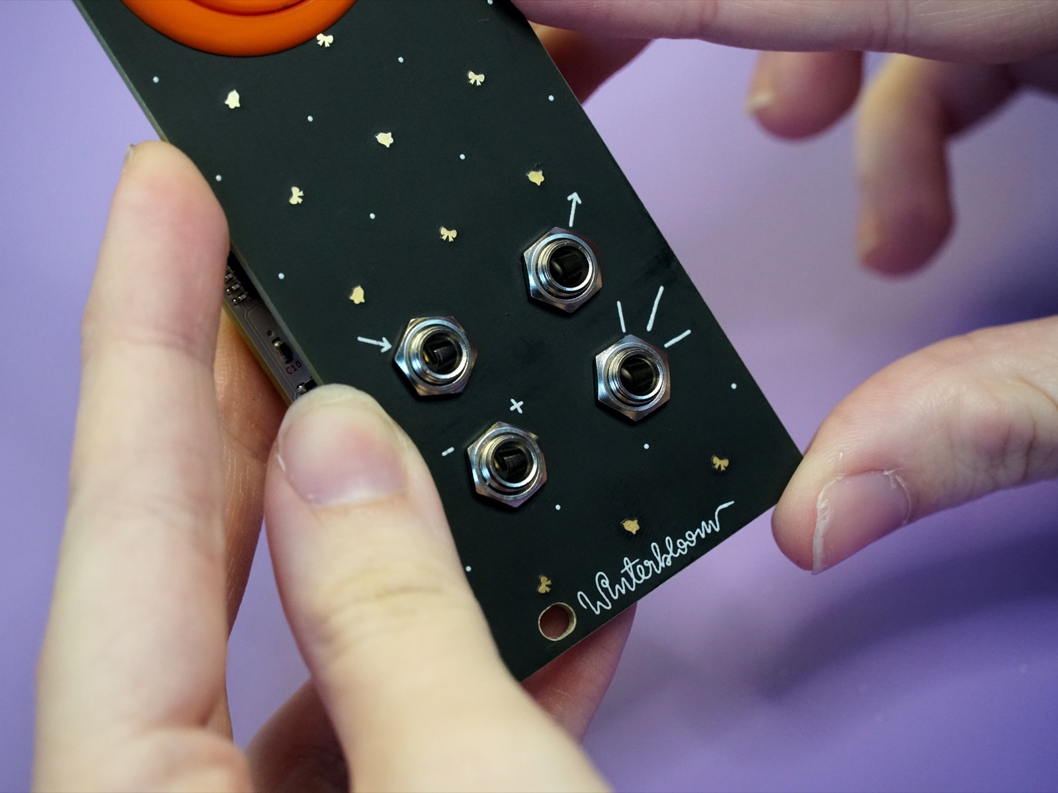
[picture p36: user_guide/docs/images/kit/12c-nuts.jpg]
Hex nuts finished


## Connect the button

Now you can connect the button's white connector to the green JST header on the board. Place it so that the tab on the connector matches the notch in the header and push it into place:

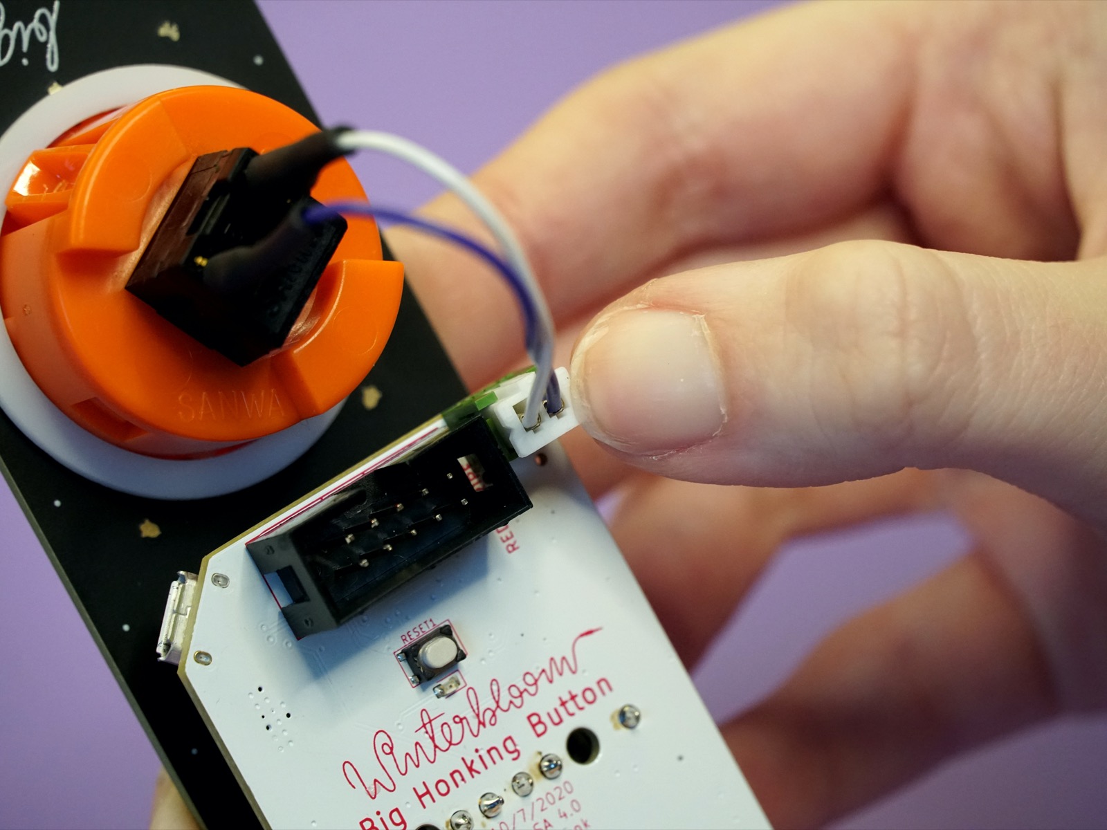
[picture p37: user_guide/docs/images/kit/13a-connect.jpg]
JST connector placed


Make sure to push the connector all the way in. It should snap in and hold in place.

## All done

Congratulations! You've finished your very own Big Honking Button!

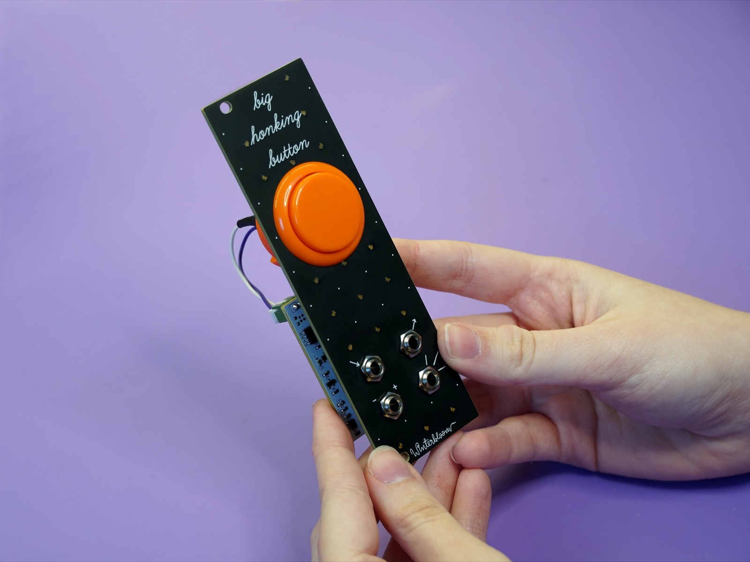
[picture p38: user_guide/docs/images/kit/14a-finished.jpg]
All done


Now that it's all put together go check out the [User's Guide](/index) and please show us your work by tweeting at [@wntrblm](https://twitter.com/wntrblm) or tagging [@wntrblm](https://instagram.com/wntrblm) in your instagram post.

[discord]: https://discord.gg/UpfqghQ

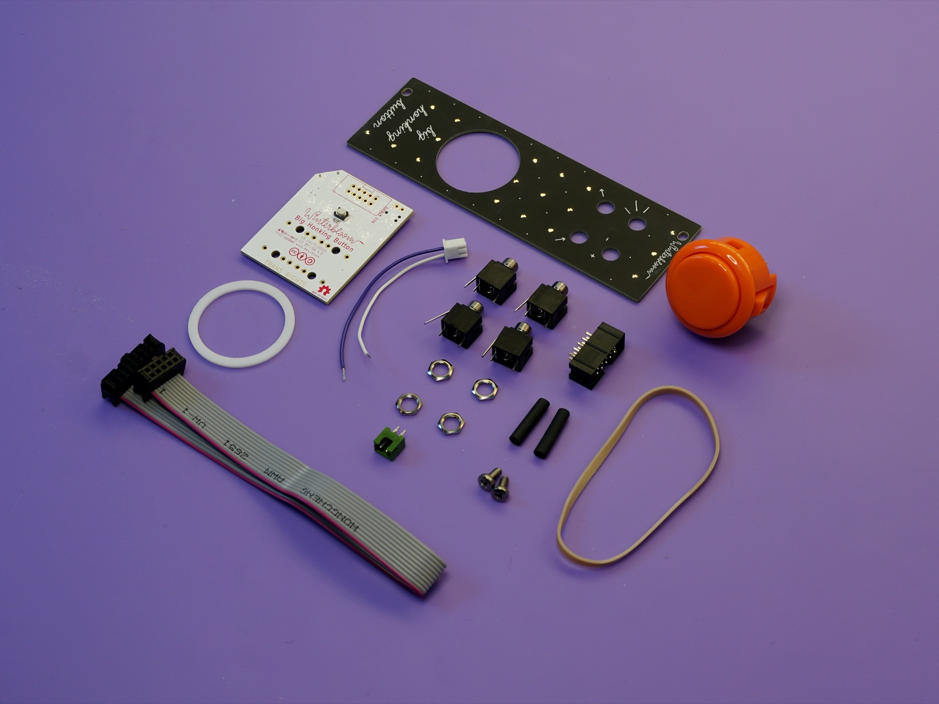
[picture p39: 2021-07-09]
user_guide/docs/images/kit/1-kit.jpg

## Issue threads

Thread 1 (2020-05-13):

Different Licenses: Readme vs. Silkscreen Board

tinyledmatrix, 2020-05-13:
Silkscreen on Bard (kicad and as far as I can See also on Twitter Image) indicates CC BY-SA 4.0. According to readme the License for the Hardware is CC BY-NC-SA 4.0. Is this difference on purpose?

theacodes, 2020-05-13:
No, the readme is incorrect (it's from an older revision). I'll update it
shortly.

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

theacodes, 2020-05-14:
Fixed!

Closed 2020-05-14.

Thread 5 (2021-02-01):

property that is only triggered on falling edge

themoep, 2021-02-01:
While trying to play a sound on button press and another on release, I made the mistake of using the `if bhb.released:` to trigger the second sound, resulting in a looping, glitchy sound while the button is not pressed.

As a workaround I added a is_pressed variable:
```
is pressed = False
while True:
    if bhb.triggered:
        is_pressed = True
        bhb.play(sample_p1, pitch_cv=bhb.pitch_in)

    if bhb.released and is_pressed:
        is_pressed = False
        bhb.play(sample_p2, pitch_cv=bhb.pitch_in)
```

It could be useful to add a stateful property that mimics this behavior of `triggered` and only is run once after the button has been released. Alternatively, this could be done in `released`.

theacodes, 2021-02-07:
This is a great idea! I'll write up a patch for it soon. :)

Closed 2021-07-22.

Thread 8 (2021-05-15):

Question

machinehistories, 2021-05-15:
I was wondering if the gate and button can be two separate functions. I was thinking of modifying the burst generator example by recording values coming in on the gate input jack. These lengths fill an array and I would also like to record the incoming cv values too. I know the length of recorded sampled values would be fairly short. Now when the button is pressed the arrays are both output on the respective jacks. Perhaps a long press button function could start and stop the record. If the gate input and button are separated then there could be double clicks and triple clicks and these could be used to change the overall functionality since you could load many examples and then change which is running on the fly with the button. Would this work.

theacodes, 2021-05-16:
Hi @machinehistories,
Yes, the button and the gate in are connected to separate pins on the microcontroller, you can check the status of the button and gate in independently using `bhb.button` and `bhb.gate_in`.

Let me know if you have any other questions, and feel free to pop by the [discord](https://winterbloom.com/contact) if you want - there's folks there (including me) that can help you.

(I'm closing this issue for now, but feel free to ask follow-up questions)

Closed 2021-05-16.

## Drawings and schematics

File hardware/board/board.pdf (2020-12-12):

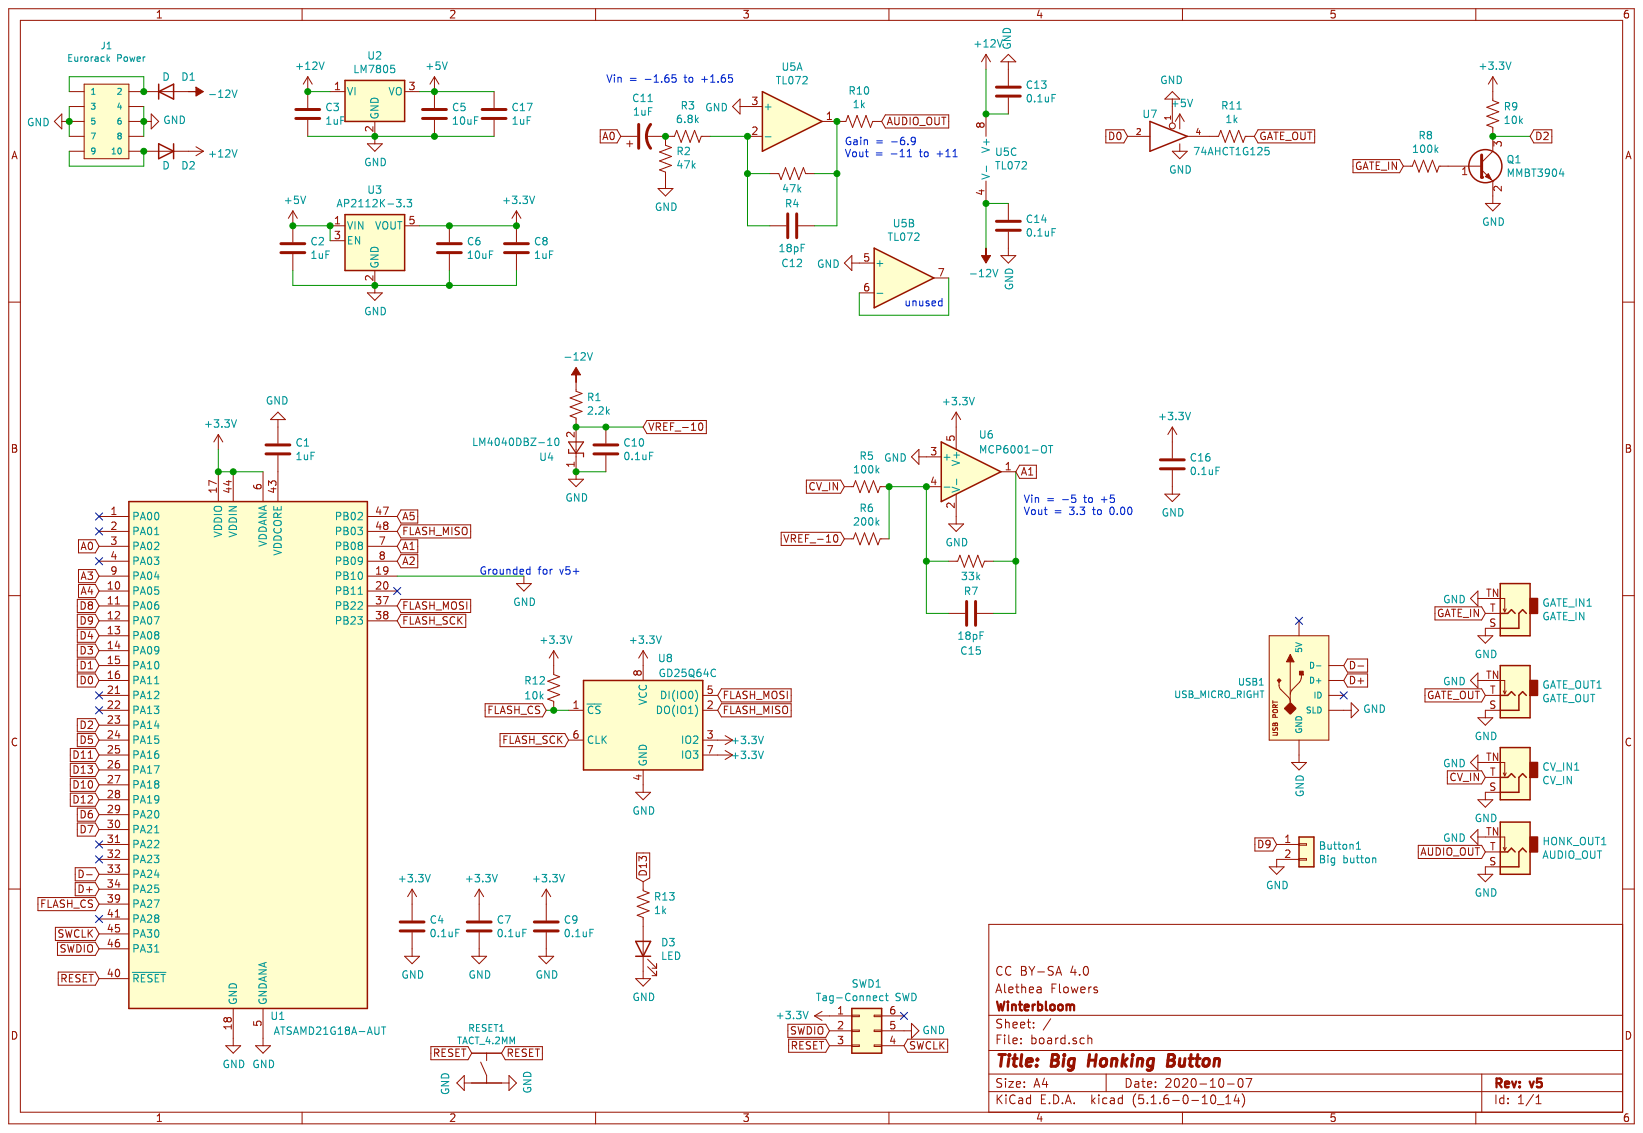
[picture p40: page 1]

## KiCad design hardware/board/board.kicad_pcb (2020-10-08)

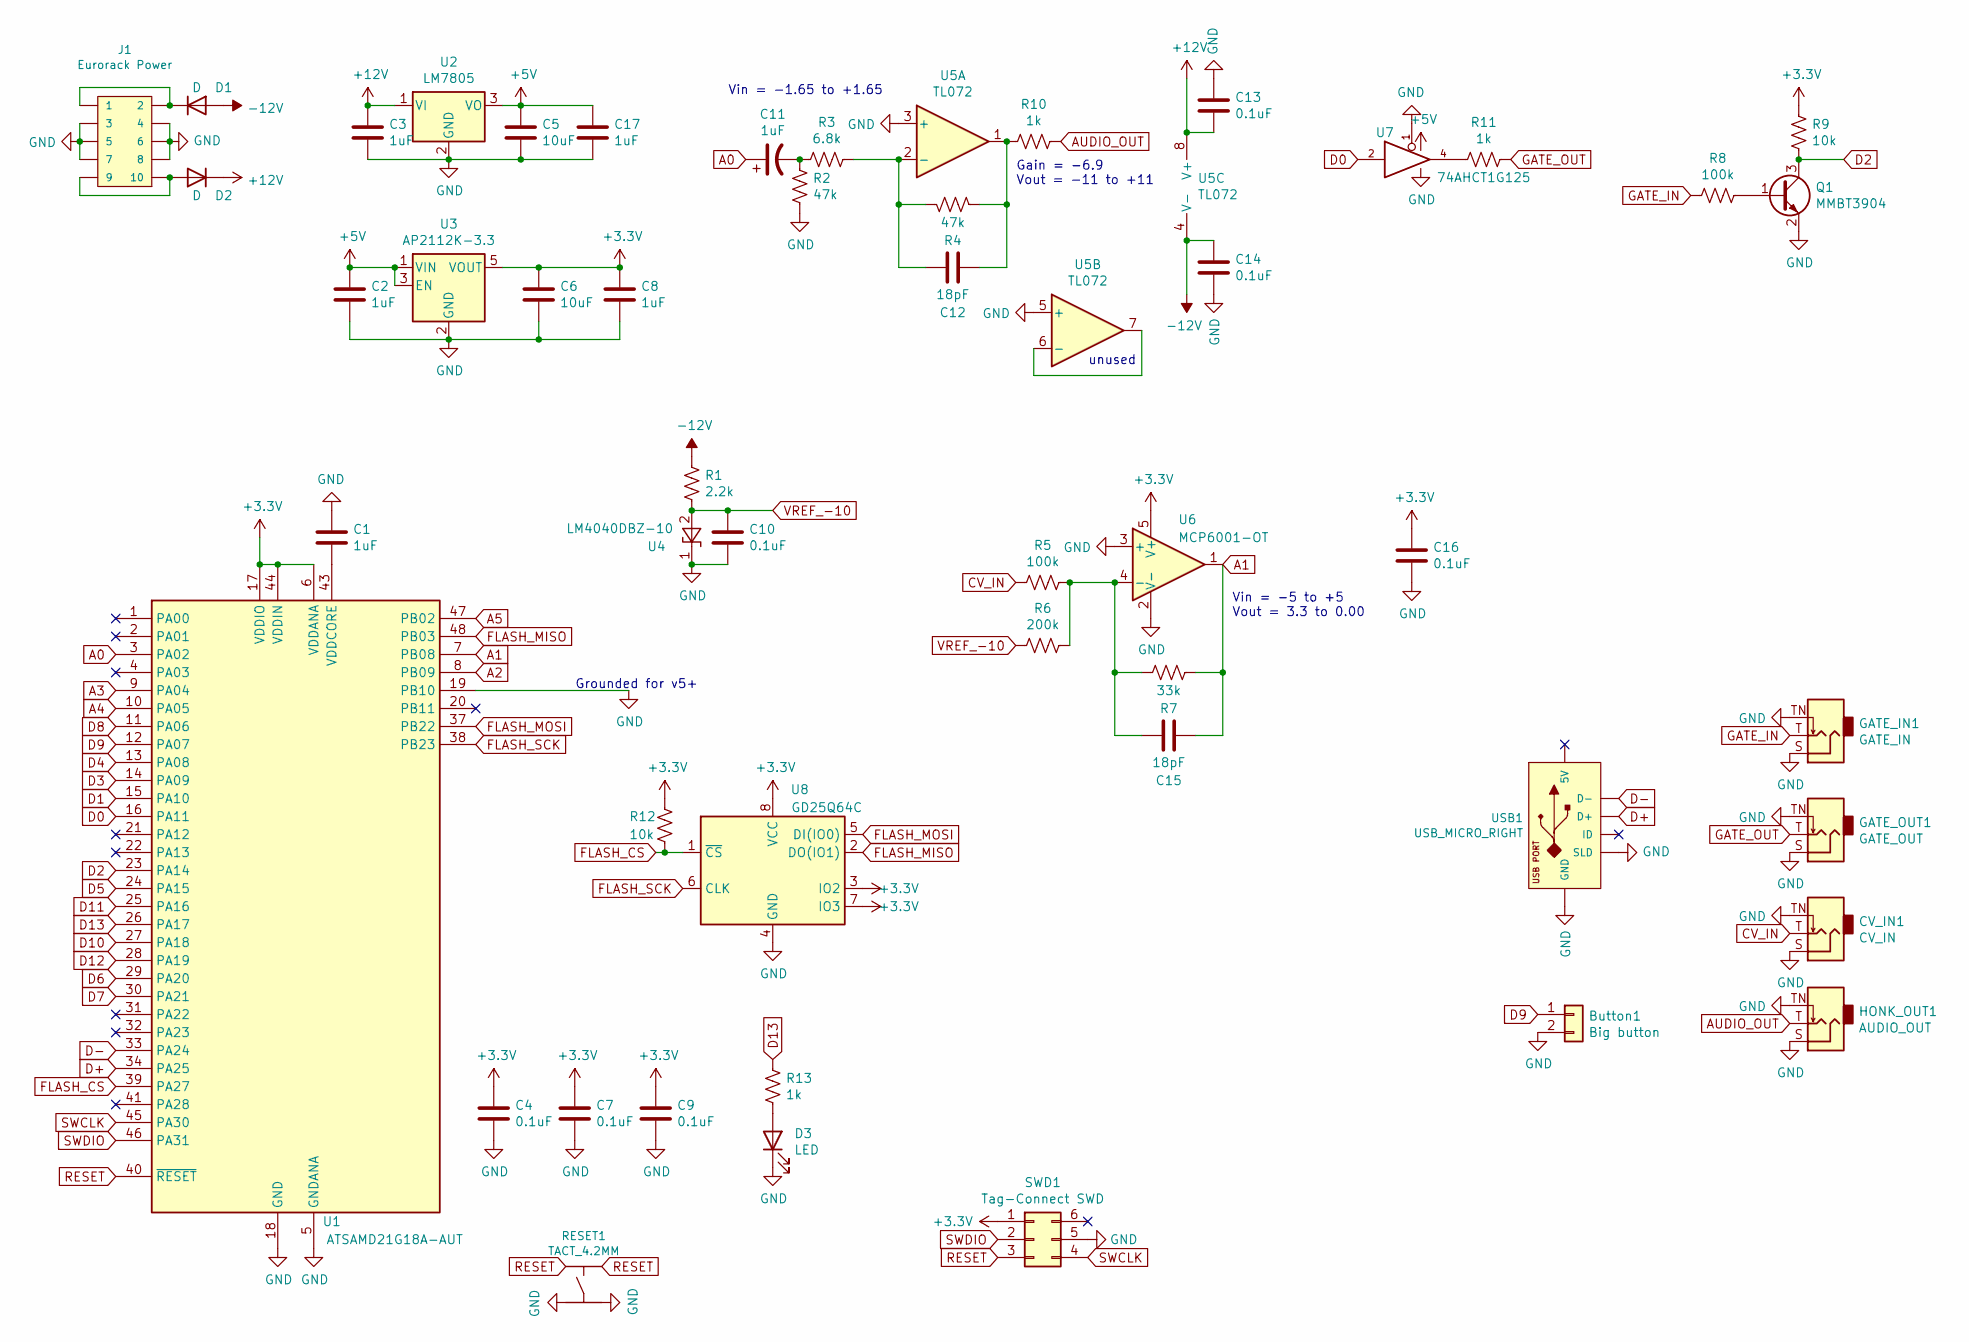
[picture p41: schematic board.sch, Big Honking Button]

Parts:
Button1: Big button; PinHeader_1x02_P2.54mm_Vertical
C1, C2, C3, C8, C11, C17: 1uF; C_0603_1608Metric_Pad1.05x0.95mm_HandSolder; mpn MF-CAP-0603-1uF
C4, C7, C9, C10, C13, C14, C16: 0.1uF; C_0603_1608Metric_Pad1.05x0.95mm_HandSolder; mpn MF-CAP-0603-0.1uF
C5, C6: 10uF; C_1206_3216Metric_Pad1.42x1.75mm_HandSolder; mpn MF-CAP-1206-10uF
C12, C15: 18pF; C_0603_1608Metric_Pad1.05x0.95mm_HandSolder; mpn MF-CAP-0603-18pF
CV_IN1: CV_IN; WQP-PJ301M-12_JACK; mpn WQP-PJ398SM
D1, D2: D; D_SOD-123; mpn MF-DIO-SOD123-1N4148
D3: LED; D_0603_1608Metric; mpn MF-LED-0603-GREEN
GATE_IN1: GATE_IN; WQP-PJ301M-12_JACK; mpn WQP-PJ398SM
GATE_OUT1: GATE_OUT; WQP-PJ301M-12_JACK; mpn WQP-PJ398SM
HONK_OUT1: AUDIO_OUT; WQP-PJ301M-12_JACK; mpn WQP-PJ398SM
J1: Eurorack Power; 2X5-SHROUDED_LOCK; mpn 61201021621
Q1: MMBT3904; SOT-23; mpn MF-DSC-SOT233-MMBT3904
R1: 2.2k; R_0603_1608Metric_Pad1.05x0.95mm_HandSolder; mpn ERA-3AED222V
R2, R4: 47k; R_0603_1608Metric_Pad1.05x0.95mm_HandSolder; mpn ERA-3AED473V
R3: 6.8k; R_0603_1608Metric_Pad1.05x0.95mm_HandSolder; mpn ERA-3AED682V
R5, R8: 100k; R_0603_1608Metric_Pad1.05x0.95mm_HandSolder; mpn ERA-3AED104V
R6: 200k; R_0603_1608Metric_Pad1.05x0.95mm_HandSolder; mpn ERA-3AEB204V
R7: 33k; R_0603_1608Metric_Pad1.05x0.95mm_HandSolder; mpn ERA-3AED333V
R9, R12: 10k; R_0603_1608Metric_Pad1.05x0.95mm_HandSolder; mpn MF-RES-0603-10K
R10, R11, R13: 1k; R_0603_1608Metric_Pad1.05x0.95mm_HandSolder; mpn MF-RES-0603-1K
RESET1: TACT_4.2MM; MF_Switches-TACT4.2MM; mpn MF-SW-TACT-4.2MM
SWD1: Tag-Connect SWD; Tag-Connect_TC2030-IDC-NL_2x03_P1.27mm_Vertical
U1: ATSAMD21G18A-AUT; TQFP-48_7x7mm_P0.5mm; mpn ATSAMD21G18A-AUT
U2: LM7805; SOT-223-3_TabPin2; mpn LM7805MP/NOPB
U3: AP2112K-3.3; SOT-23-5; mpn AP2112K-3.3TRG1
U4: LM4040DBZ-10; SOT-23; mpn LM4040DIM3-10.0/NOPB
U5: TL072; TSSOP-8_4.4x3mm_P0.65mm; mpn TL072CPWR
U6: MCP6001-OT; SOT-23-5; mpn MCP6001T-I/OT
U7: 74AHCT1G125; SOT-23-5; mpn SN74AHCT1G125DBVR
U8: GD25Q64C; SOIC-8_5.23x5.23mm_P1.27mm; mpn GD25Q64CSIGR
USB1: USB_MICRO_RIGHT; MF_Connectors-MICROUSB-RIGHT; mpn MF-CON-MICROUSB-RIGHT

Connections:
+3V3: C4.1, C6.1, C7.1, C8.1, C9.1, C16.1, R9.2, R12.1, SWD1.1, U1.6 (VDDANA), U1.17 (VDDIO), U1.36 (VDDIO), U1.44 (VDDIN), U3.5 (VOUT), U6.5 (V+), U8.3 (IO2), U8.7 (IO3), U8.8 (VCC)
+5V: C2.1, C5.1, C17.1, U2.3 (VO), U3.1 (VIN), U3.3 (EN), U7.5 (VCC)
+12V: C3.1, C13.2, D2.1 (K), U2.1 (VI), U5.8 (V+)
-12V: C14.1, D1.2 (A), R1.2, U5.4 (V-)
A0: C11.1, U1.3 (PA02)
A1: C15.1, R7.1, U1.7 (PB08), U6.1
A2: U1.8 (PB09)
A3: U1.9 (PA04)
A4: U1.10 (PA05)
A5: U1.47 (PB02)
AUDIO_OUT: HONK_OUT1.T, R10.1
CV_IN: CV_IN1.T, R5.2
D0: U1.16 (PA11), U7.2
D1: U1.15 (PA10)
D2: Q1.3 (C), R9.1, U1.23 (PA14)
D3: U1.14 (PA09)
D4: U1.13 (PA08)
D5: U1.24 (PA15)
D6: U1.29 (PA20)
D7: U1.30 (PA21)
D8: U1.11 (PA06)
D9: Button1.1, U1.12 (PA07)
D10: U1.27 (PA18)
D11: U1.25 (PA16)
D12: U1.28 (PA19)
D13: R13.2, U1.26 (PA17)
D+: U1.34 (PA25), USB1.3 (D+)
D-: U1.33 (PA24), USB1.2 (D-)
FLASH_CS: R12.2, U1.39 (PA27), U8.1 (~CS)
FLASH_MISO: U1.48 (PB03), U8.2 (DO(IO1))
FLASH_MOSI: U1.37 (PB22), U8.5 (DI(IO0))
FLASH_SCK: U1.38 (PB23), U8.6 (CLK)
GATE_IN: GATE_IN1.T, R8.2
GATE_OUT: GATE_OUT1.T, R11.1
GND: Button1.2, C1.1, C2.2, C3.2, C4.2, C5.2, C6.2, C7.2, C8.2, C9.2, C10.2, C13.1, C14.2, C16.2, C17.2, CV_IN1.S, CV_IN1.TN, D3.1 (K), GATE_IN1.S, GATE_IN1.TN, GATE_OUT1.S, GATE_OUT1.TN, HONK_OUT1.S, HONK_OUT1.TN, J1.3, J1.4, J1.5, J1.6, J1.7, J1.8, Q1.2 (E), R2.1, RESET1.3, RESET1.4, SWD1.5, U1.5 (GNDANA), U1.18 (GND), U1.19 (PB10), U1.35 (GND), U1.42 (GND), U2.2 (GND), U3.2 (GND), U4.1 (K), U5.3 (+), U5.5 (+), U6.2 (V-), U6.3 (+), U7.1, U7.3 (GND), U8.4 (GND), USB1.5 (GND), USB1.S1 (SLD), USB1.S2 (SLD), USB1.S3 (SLD), USB1.S4 (SLD), USB1.S5 (SLD), USB1.S6 (SLD)
unnamed: C1.2, U1.43 (VDDCORE)
unnamed: C11.2, R2.2, R3.2
unnamed: C12.1, R4.2, R10.2, U5.1
unnamed: C12.2, R3.1, R4.1, U5.2 (-)
unnamed: C15.2, R5.1, R6.1, R7.2, U6.4 (-)
unnamed: D1.1 (K), J1.1, J1.2
unnamed: D2.2 (A), J1.9, J1.10
unnamed: D3.2 (A), R13.1
unnamed: Q1.1 (B), R8.1
unnamed: R11.2, U7.4
unnamed: U5.6 (-), U5.7
RESET: RESET1.1, RESET1.2, SWD1.3, U1.40 (~RESET)
SWCLK: SWD1.4, U1.45 (PA30)
SWDIO: SWD1.2, U1.46 (PA31)
VREF_-10: C10.1, R1.1, R6.2, U4.2 (A)

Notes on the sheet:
Vin = -1.65 to +1.65
Gain = -6.9 Vout = -11 to +11
Vin = -5 to +5 Vout = 3.3 to 0.00
unused
Grounded for v5+

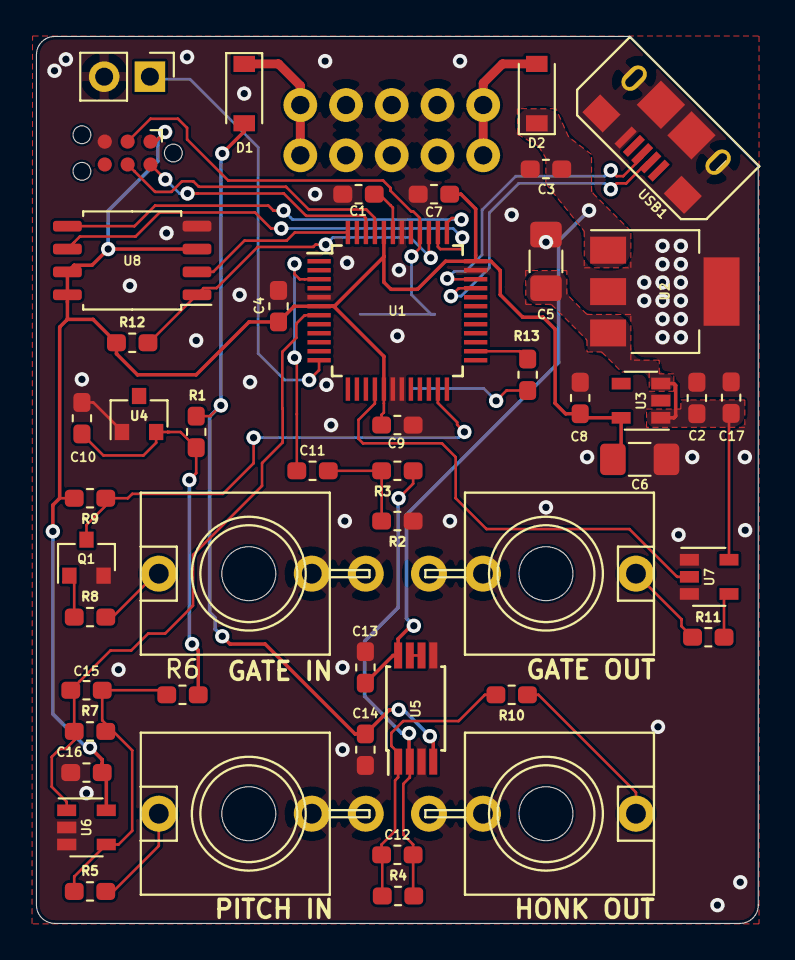
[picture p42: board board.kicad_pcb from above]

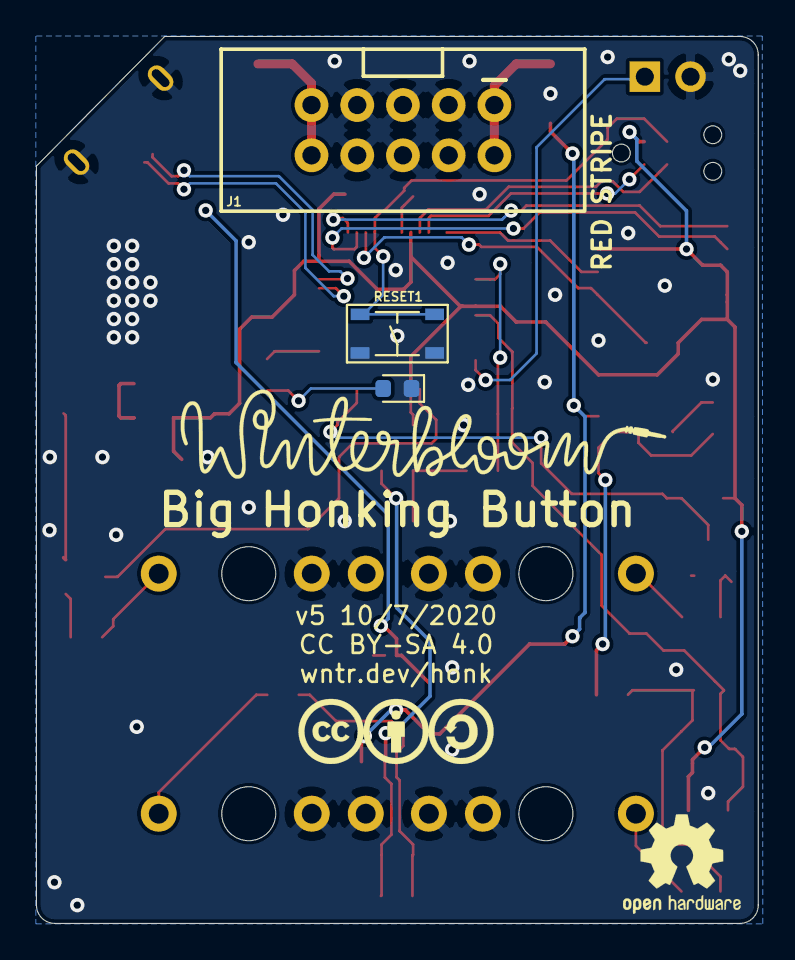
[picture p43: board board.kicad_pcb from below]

Board: 2 copper layers, 40.1 x 49.3 mm, 51 parts (3 on the bottom side), 36 nets.

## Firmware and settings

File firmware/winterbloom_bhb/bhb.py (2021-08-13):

# The MIT License (MIT)
#
# Copyright (c) 2020 Alethea Flowers for Winterbloom
#
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
import audiocore
import audioio
import board
import digitalio
import winterbloom_voltageio

try:
    import _bhb
except ImportError:
    raise RuntimeError("This BHB library requires CircuitPython >= 6.0.0")


def _detect_board_revision():
    v5pin = digitalio.DigitalInOut(board.V5)
    v5pin.switch_to_input(pull=digitalio.Pull.UP)

    # Pulled low on v5+, pull-up will make it true
    # on <=v4.
    if not v5pin.value:
        return 5
    else:
        return 4


class _AnalogIn:
    def __init__(self):
        _bhb.init_adc()

    @property
    def value(self):
        return _bhb.read_adc()


class _InputState:
    def __init__(self, pin):
        self._in = digitalio.DigitalInOut(pin)
        self._in.switch_to_input(pull=digitalio.Pull.UP)
        self.state = False
        self.last_state = False

    def update(self):
        self.last_state = self.state
        self.state = not self._in.value

    @property
    def rising_edge(self):
        return self.state and not self.last_state

    @property
    def falling_edge(self):
        return not self.state and self.last_state

    @property
    def value(self):
        return self.state

    pressed = rising_edge
    triggered = rising_edge
    released = falling_edge
    held = value
    __bool__ = value


class BigHonkingButton:
    def __init__(self):
        self.board_revision = _detect_board_revision()
        self._button = _InputState(board.BUTTON)
        self._gate_in = _InputState(board.GATE_IN)
        self._gate_out = digitalio.DigitalInOut(board.GATE_OUT)
        self._gate_out.switch_to_output()

        self._pitch_in = winterbloom_voltageio.VoltageIn(_AnalogIn())

        if self.board_revision >= 5:
            self._pitch_in.direct_calibration(
                {4068: -5.0, 3049: -2.5, 2025: 0, 1001: 2.5, 8: 5.0}
            )
            self.min_cv = -5.0
            self.max_cv = 5.0
        else:
            self._pitch_in.direct_calibration(
                {4068: -2.0, 3049: -1.0, 2025: 0, 1001: 1.0, 8: 2.0}
            )
            self.min_cv = -2.0
            self.max_cv = 2.0

        self.audio_out = audioio.AudioOut(board.HONK_OUT)

    def update(self):
        self._gate_in.update()
        self._button.update()
        return True

    @property
    def button(self):
        return self._button

    @property
    def gate_in(self):
        return self._gate_in

    @property
    def pitch_in(self):
        return self._pitch_in.voltage

    @property
    def gate_out(self):
        return self._gate_out.value

    @gate_out.setter
    def gate_out(self, value):
        self._gate_out.value = value

    @property
    def triggered(self):
        return self._button.triggered or self._gate_in.triggered

    @property
    def released(self):
        return self._button.released or self._gate_in.released

    def load_sample(self, path):
        return audiocore.WaveFile(open(path, "rb"))

    def play(self, sample, pitch_cv=None, loop=False):
        if pitch_cv is not None:
            sample_rate = min(int(44100 * pow(2, pitch_cv)), (350000 - 1))
            sample.sample_rate = sample_rate
        self.audio_out.stop()
        self.audio_out.play(sample, loop=loop)

    def stop(self):
        self.audio_out.stop()

    def select_from_list_using_cv(self, list, cv, low=None, high=None):
        if low is None:
            low = self.min_cv
        if high is None:
            high = self.max_cv

        cv = min(high, max(low, cv))
        count = len(list) - 1
        span = high - low
        value = cv - low
        index = int((value / span) * count)
        return list[index]

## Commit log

2020-03-03 Add initial hardware design
    [User Library-PJ301M-12 Thonkiconn v0_2.STEP, board.kicad_pcb, board.sch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]
2020-03-05 Fix incorrect resistor values
    [board.kicad_pcb, board.sch]
2020-03-20 Fix issues found in the first prototype
    [board.kicad_pcb, board.sch, wurth-61201021621.step]
2020-04-24 Add firmware
    [.isort.cfg]
2020-04-24 Fix pinout on zener diode
    [board.kicad_pcb, board.sch]
2020-05-14 Update board
    [board.sch]
2020-06-23 Add more samples, add examples, add ability to loop samples
2020-07-01 Fix link to random sample
2020-07-18 Update docs to say 44.1kHz instead of 22kHz (#3)
    Hello! I just got this module (it's fantastic!), and uploaded to it the latest release, but as I was trying to load my own samples onto it, I found two things which seem to have drifted from these docs:
    1. The sample that comes with it is called `honk.wav` and not `sample.wav` -- was an earlier version called `sample.wav`?
    2. The `honk.wav` audio file is 16-bit signed mono WAV at _44.1kHz_ and not 22kHz... I found this out the hard way because I kept loading my own samples at 22kHz and wondering why they were playing back at a higher pitch than I expected. 😅 When I transcoded my audio files to 44.1kHz 16-bit signed mono WAVs, they sudde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
2020-10-08 Board revision v5
    - Switch to 8mb flash
    - Switch all resistors to 0603
    - Change CV input to -5 to +5
    [board.kicad_pcb, board.sch]
2020-10-09 Remove gerbers
2020-11-19 Fix use of WaveFile to support CircuitPython 6.0
    [bhb.py]
2020-12-12 Add PDF of the schematic and a pre-submit hook to make sure it doesn't go out of sync.
    [board.sch]
2021-01-14 Work around circuitpython file copying issue
    [bhb.py]
2021-02-13 Fix bug where high pitch CV would cause the sample rate to be too high. (#7)
    [bhb.py]
2021-02-13 Switch factory setup script to use wintertools
2021-07-08 examples: Add CV select sample (#9)
    * Add files via upload
    * Update CV_select.py
    * firmware: Add select_from_list_using_cv helper
    * examples: Add CV select example
2021-07-22 firmware: Add the ability to track pressed (triggered) and released for gate in and the button independently.
    Note: This is a *breaking* change. `bhb.update()` must be called for every loop in `code.py`.
    To upgrade, just replace:
    ```
    while True:
    ```
    with
    ```
    while bhb.update():
    ```
    in code.py. The examples have all been updated.
    Added two additional samples for separate press & release and separate button & gate.
    Closes #5
    [bhb.py]
2021-07-22 user guide: Update samples list
2021-08-13 firmware: Fix off-by-one error in select_from_list_using_cv
    [bhb.py]
2022-01-14 added long hong code and samples (#11)
2022-11-18 Create silent_cycle.py (#13)
    Cycle silently though your samples (all samples in /sample directory) with the honking button and play them with the trigger input.
2025-01-30 Hardware: added faceplate
    [faceplate.kicad_pcb]

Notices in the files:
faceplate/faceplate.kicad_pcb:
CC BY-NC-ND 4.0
